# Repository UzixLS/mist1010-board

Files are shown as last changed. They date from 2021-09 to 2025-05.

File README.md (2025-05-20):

## MIST.1010
10x10cm PCB variant of [MIST FPGA](https://github.com/mist-devel/mist-board/wiki) project

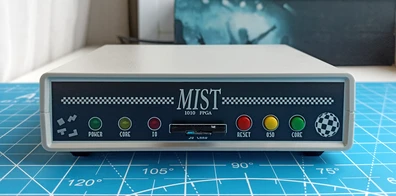
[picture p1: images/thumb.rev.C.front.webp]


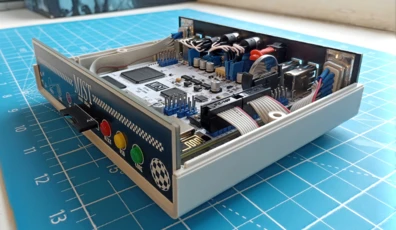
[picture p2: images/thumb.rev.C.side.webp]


[[More photos]](images/README.md)

Tech specs:
- EP3C25E144 FPGA
- 32/64Mb SDRAM
- VGA/RGB video output
- Composite video + audio output via 3.5 jack connector (raspberry-pi compatible pinout)
- 4xUSB ports for keyboard, mouse and joysticks
- 2xDB-9 ports for Amiga mouse and joysticks
- SD/microSD card slot
- RTC (clock) with battery
- Tape input / output
- ESP8266 WiFi module
- MIDI input and output (starting from rev.C)
- Type C (starting from rev.D) or MicroUSB power supply
- Board optimized for G738 and G706 cases

Some random photos: [link](https://cloud.err200.net/index.php/s/73TR85tYZkMm8Ax?path=%2Fmist1010)

### Changelog
* Rev.A - first revision. Please note the [errata](pcb/rev.A/ERRATA.txt).
* Rev.A1:
    * fixed all rev.A issues
    * LM3940IS-3.3 replaced to NCP1117-3.3
    * sound output circuit has been replaced with the original one from the MIST 1.3 circuit
    * C39, C40, C80 tantalum capacitors has been replaced by aluminum electrolytic capacitors
    * added ARM's "erase" testpoint
    * removed useless internal speaker
* Rev.A2:
	* C41, C68, C69 10uf ceramic capacitors has been replaced with 22uf tantalum
    * added C74 ceramic capacitor near ESP-01 module
* Rev.B:
    * added ESP-12E/F footprint (ESP-01 is still an option)
    * added MIDI input and output
    * removed U11 - AD724 encoder
    * added resistors-based CVBS (Y+C) video circuit
    * added JP4 solder jumper to disconnect CVBS circuit from 3.5mm jack
    * added U16 buffer with dedicated power source U17 for audio 1-bit DAC
    * added USB 2.54mm header
    * tuned SDRAM traces length for better match with MIST v1.3 PCB
    * changed U6 (attiny) footprint from DIP to SOIC
    * changed Y1 and Y2 footprints from THT to SMD
    * changed 1117-3.3 footprint from TO-252-2 to SOT-223-3
    * added U12 dedicated +3.3V power source for SD card and WiFi
    * 3mm front leds replaced by 5mm
    * R38 (VGA's +5V 0Ω resistor) has been replaced by solder jumper
    * changed tape header pinout
    * pcb corners are rounded now
    * experimental reset circuit based on MAX809
    * various changes in board layout
* Rev.C:
    * used USB Type C instead of Micro USB
    * PJ-320 3.5mm jack replaced by PJ-322
    * added solder jumper to select 3.5mm jack CVBS pinout
    * improved power distribution for FPGA chip
    * removed U16 buffer for DAC as it didn't bring any benefits
    * marked C27 and C28 as DNP
    * reverted to old reset circuit
    * various minor changes in board layout
* Rev.C1:
    * changed R47 from 220Ω to 1kΩ to reduce power led brightness
    * slightly moved C87 and C89

### Useful links
* MIST wiki: [link](https://github.com/mist-devel/mist-board/wiki)
* MIST cores and firmwares: [link](https://github.com/mist-devel/mist-binaries)

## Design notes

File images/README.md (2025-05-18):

# Gallery

## Revision C

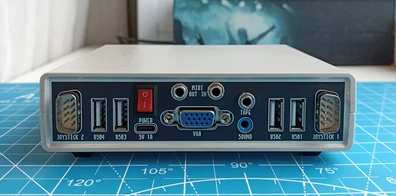
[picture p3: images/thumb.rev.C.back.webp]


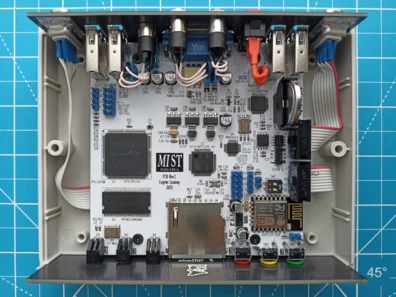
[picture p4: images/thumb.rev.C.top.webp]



## Revision B
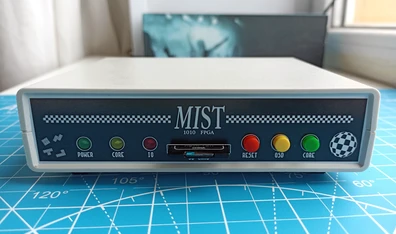
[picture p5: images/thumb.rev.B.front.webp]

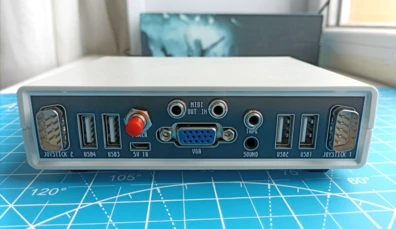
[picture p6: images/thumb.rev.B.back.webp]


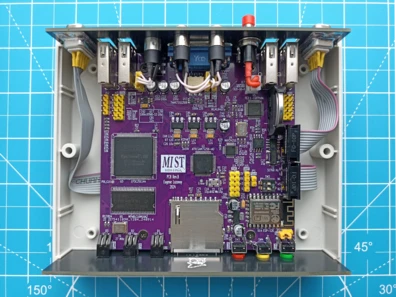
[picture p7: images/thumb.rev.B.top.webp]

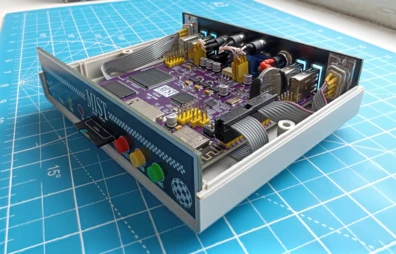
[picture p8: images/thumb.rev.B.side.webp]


## Revision A
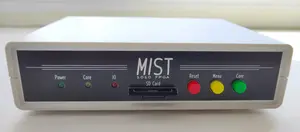
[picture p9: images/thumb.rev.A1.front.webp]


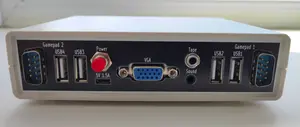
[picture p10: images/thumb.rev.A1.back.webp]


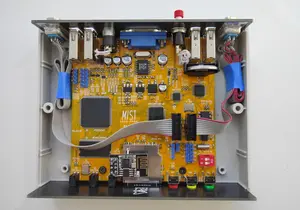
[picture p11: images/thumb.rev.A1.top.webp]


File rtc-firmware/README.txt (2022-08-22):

https://github.com/harbaum/I2C-Tiny-USB

Fuse Low Byte: 0xE0
Fuse High Byte: 0x5D

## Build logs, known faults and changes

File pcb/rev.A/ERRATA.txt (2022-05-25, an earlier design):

1. VGA_x0 .. VGA_x5 resistors are reversed by value. Should be:
   VGA_x5 - 1k + 1.1k in parallel
   VGA_x4 - 1.1k
   VGA_x3 - 2.2k
   VGA_x2 - 4.3k
   VGA_x1 - 9.1k
   VGA_x0 - 18k
2. USB_DP and USB_DN signals are swapped.
3. R49 is connected to RTC_DP net, should be RTC_DN.
4. USB, VGA and jack 3.5 connectors are placed too deep. Jack 3.5 should be soldered 2-3mm ahead it's footprint.
5. LS1 shouldn't be mounted.
6. Tape and WiFi isn't possible to use at the same time. If you want to install WiFi module - do not mount R59.

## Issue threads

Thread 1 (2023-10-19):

Some help needed with Audio jack connection for tape.

AmiManga, 2023-10-19:
Hello,
I am trying to figure out how wo connect tape connector and how to make the audio cable?
I assume this is stereo jack? Where does the TAPE_OUT go? And how about TAPE_IN?
Should I split this after to two mono jacks like this? : https://www.ebay.ca/itm/383787499804

Is this correct?

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

Cheers,

Ranko

UzixLS, 2023-10-21:
Which cable to use / how to make cable - it completely depends on your tape equipment, see it's manual.
In MIST 1010 tape in/out is populated just on pin header, so can be connected in any way you need.

AmiManga, 2023-10-22:
Thank you for your reply. So if I understand correctly, TAPE_OUT goes to MIC (on the cassette player) and TAPE_IN goes to EAR (on the cassette player)? Is this correct? OR other way around?

Cheers,

R.

UzixLS, 2023-10-24:
This is probably correct.

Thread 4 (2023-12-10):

RTC implementation?

AmiManga, 2023-12-10:
Regarding RTC,

I was able to setup the time and it works just fine!
However while system is off, clock does not measure time, just remembers time when system was powered off.
Is this proper behaviour or am I missing something? Should clock run all the time?

Cheers,

R.

UzixLS, 2023-12-10:
RTC should count time even when system powered off.
Check battery voltage - it must be between 2.0V and 3.5V for proper operation.

AmiManga, 2023-12-10:
It appears that there was a firmware corruption in the ATtiny45. Fortunately, after re-flashing the firmware, everything is functioning correctly even after powering off. I recall that the clock initially performed well in offline mode. Glad to know it wasn't just my imagination!

Thank you

R.

Closed 2023-12-10.

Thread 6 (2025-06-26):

Trouble loading fpga core

svpantazi, 2025-06-26:
Hello,

I am trying to boot MIST1010. The FPGA NSTATUS does not change to OK and i receive Fatal error 3 (3 blinks, one longer +2 short).  I used a AT91SAM7S512 (512kb Flash) instead of the 256 kb in the schematic and the alternative micro SD card slot footprint (I notice that does not come with a SD_WP pin). The parts are identical as far as I can tell, except for the amount of Flash. I also prepared an SD card, according to instructions. I am looking for any suggestions you may have.
Below is the serial debug I receive:

Minimig by Dennis van Weeren
ARM Controller by Jakub Bednarski

Version ATH250604

SDHC card detected
spiclk: 24 MHz
usb_init
usb_hw_init
max3421e_init()
Chip revision: 13
busprobe()
usb_reset_state
Partition Count: 1
Partition: 0  Start: 8192  Size: 62325760
Partition type: EXFAT
fat_size: 7616
fat_number: 1
fat_start: 10240
root_directory_start: 7
dir_entries: 0
data_start: 18432
cluster_size: 64
free_clusters: 4294967295
ChangeDirectoryName: / -> / = /
Loading SYSTEM.FNT
Invalid SYSTEM.FNT size!
debug_mode = 0
INI_PARSER : Can't open file /CORE.ARC !
ARC CONF STR:
INI_PARSER : Can't open file /MISTCFG.INI !
loaded_from_usb = 0
FPGA bitstream file CORE.RBF opened, file size = 385575
[FPGA NSTATUS is NOT high!
Fatal error: 3

svpantazi, 2025-06-26:
Nevermind, the trouble with loading FPGA core and the errors above was simply caused by my not soldering the FPGA bottom pad to the board.

Closed 2025-06-26.

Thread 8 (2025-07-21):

RTC not work !

nicolaebizi, 2025-07-21:
Hello
Today I turned on the MIST1010 and I have only one problem! The clock counts the seconds from 80 to 139, and if I turn off the power it stays there and doesn't continue counting.

nicolaebizi, 2025-07-23:
This proves that in the firmware register 0 with bit 7 is sent to the display, in the Arduino library it is corrected -&x7f- and then ok is displayed for the second.
Don't beat around the bush if it's not like that, I'm a beginner!

svpantazi, 2025-07-23:
After inspecting the code and serial debug messages from AT91 firmware it appears that all USB device classes are indeed supposed to be initialized in the usb_configure() call. initializing USB classes proceds in this order, the hub class that ends up no accepted (with "not a hub!" message) followed by the usb HID class which manages to initialize the keyboard and mouse. Initialization of the other classes listed (xbox, asix, storage, usbrtc and pl2003) depends strongly of what is plugged into the hub and can be chaotic at times, only to be settled by additional resets. I am suggesting that listing the usbrtc earlier in the list (currently at index 5 in the list, since storage class is not enabled), maybe even before HID, may accomplish something (list the current date and time) but not the CH bit initialization which may need to be done once only to enable the clock oscillator.

** serial debug excerpt:
[...]
trying to init class 0
usb_hub_init()
not a hub!
 -> not accepted :-(
trying to init class 1
HID: usb_hid_init(3)
HID: iface is HID
HID: HID protocol is MOUSE
HID:  -> report descriptor size = 46
HID: endpoint 1, interval = 10ms
HID: HID report descriptor:
0000: 05 01 09 02 a1 01 09 01 a1 00 05 09 19 01 29 03   ..............).
0010: 15 00 25 01 95 08 75 01 81 02 05 01 09 30 09 31   ..%.�.u.�....0.1
0020: 09 38 15 81 25 7f 75 08 95 03 81 06 c0 c0         .8.�%.u.�����.�.��
HIDP: USAGE_PAGE(1/0x1)
HIDP:  -> Generic Desktop

*** [multiple HID mesages]

HIDP:   - report 0 is usable
MOUSE: report type = 1, id = 0, size = 4
HID configured
 -> accepted :-)
status change on port 5, 0x10301
Status of port 5:
 connected
 powered
 low speed
Changes on port 5:
 connected
 dev 1: port 5 connect!
usb_release_device(parent=1, port=5
resetting port 5
status change on port 5, 0x100303
Status of port 5:
 connected
 enabled
 powered
 low speed
Changes on port 5:
 reset
 port 5 reset complete!
usb_configure(parent=1 port=5 lowspeed=1)
using free entry at 3
Setting addr 4
usb_set_addr(new=4)
USB vendor ID: 0403, product ID: C631
wLangId: 0409
trying to init class 0
usb_hub_init()
not a hub!
 -> not accepted :-(
trying to init class 1
HID: usb_hid_init(4)
HID: no hid interfaces found
 -> not accepted :-(
trying to init class 2
 -> not accepted :-(
trying to init class 3
 -> not accepted :-(
trying to init class 4
 -> not accepted :-(
trying to init class 5
time: 19:07:80
date: 18.07.25
 -> accepted :-)
** end of serial debug

As others reported, it appears that the entered date and time date is being stored and persists but RTC does no update. Which prompted me to actually set the seconds value to 0, which made the clock start!

nicolaebizi, 2025-07-23:
ok

Closed 2025-07-23.

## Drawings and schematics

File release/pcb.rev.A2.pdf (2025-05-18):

1 | 2 | 3 | 4 | 5 | 6 | 7 | 8 | 9 | 10

A

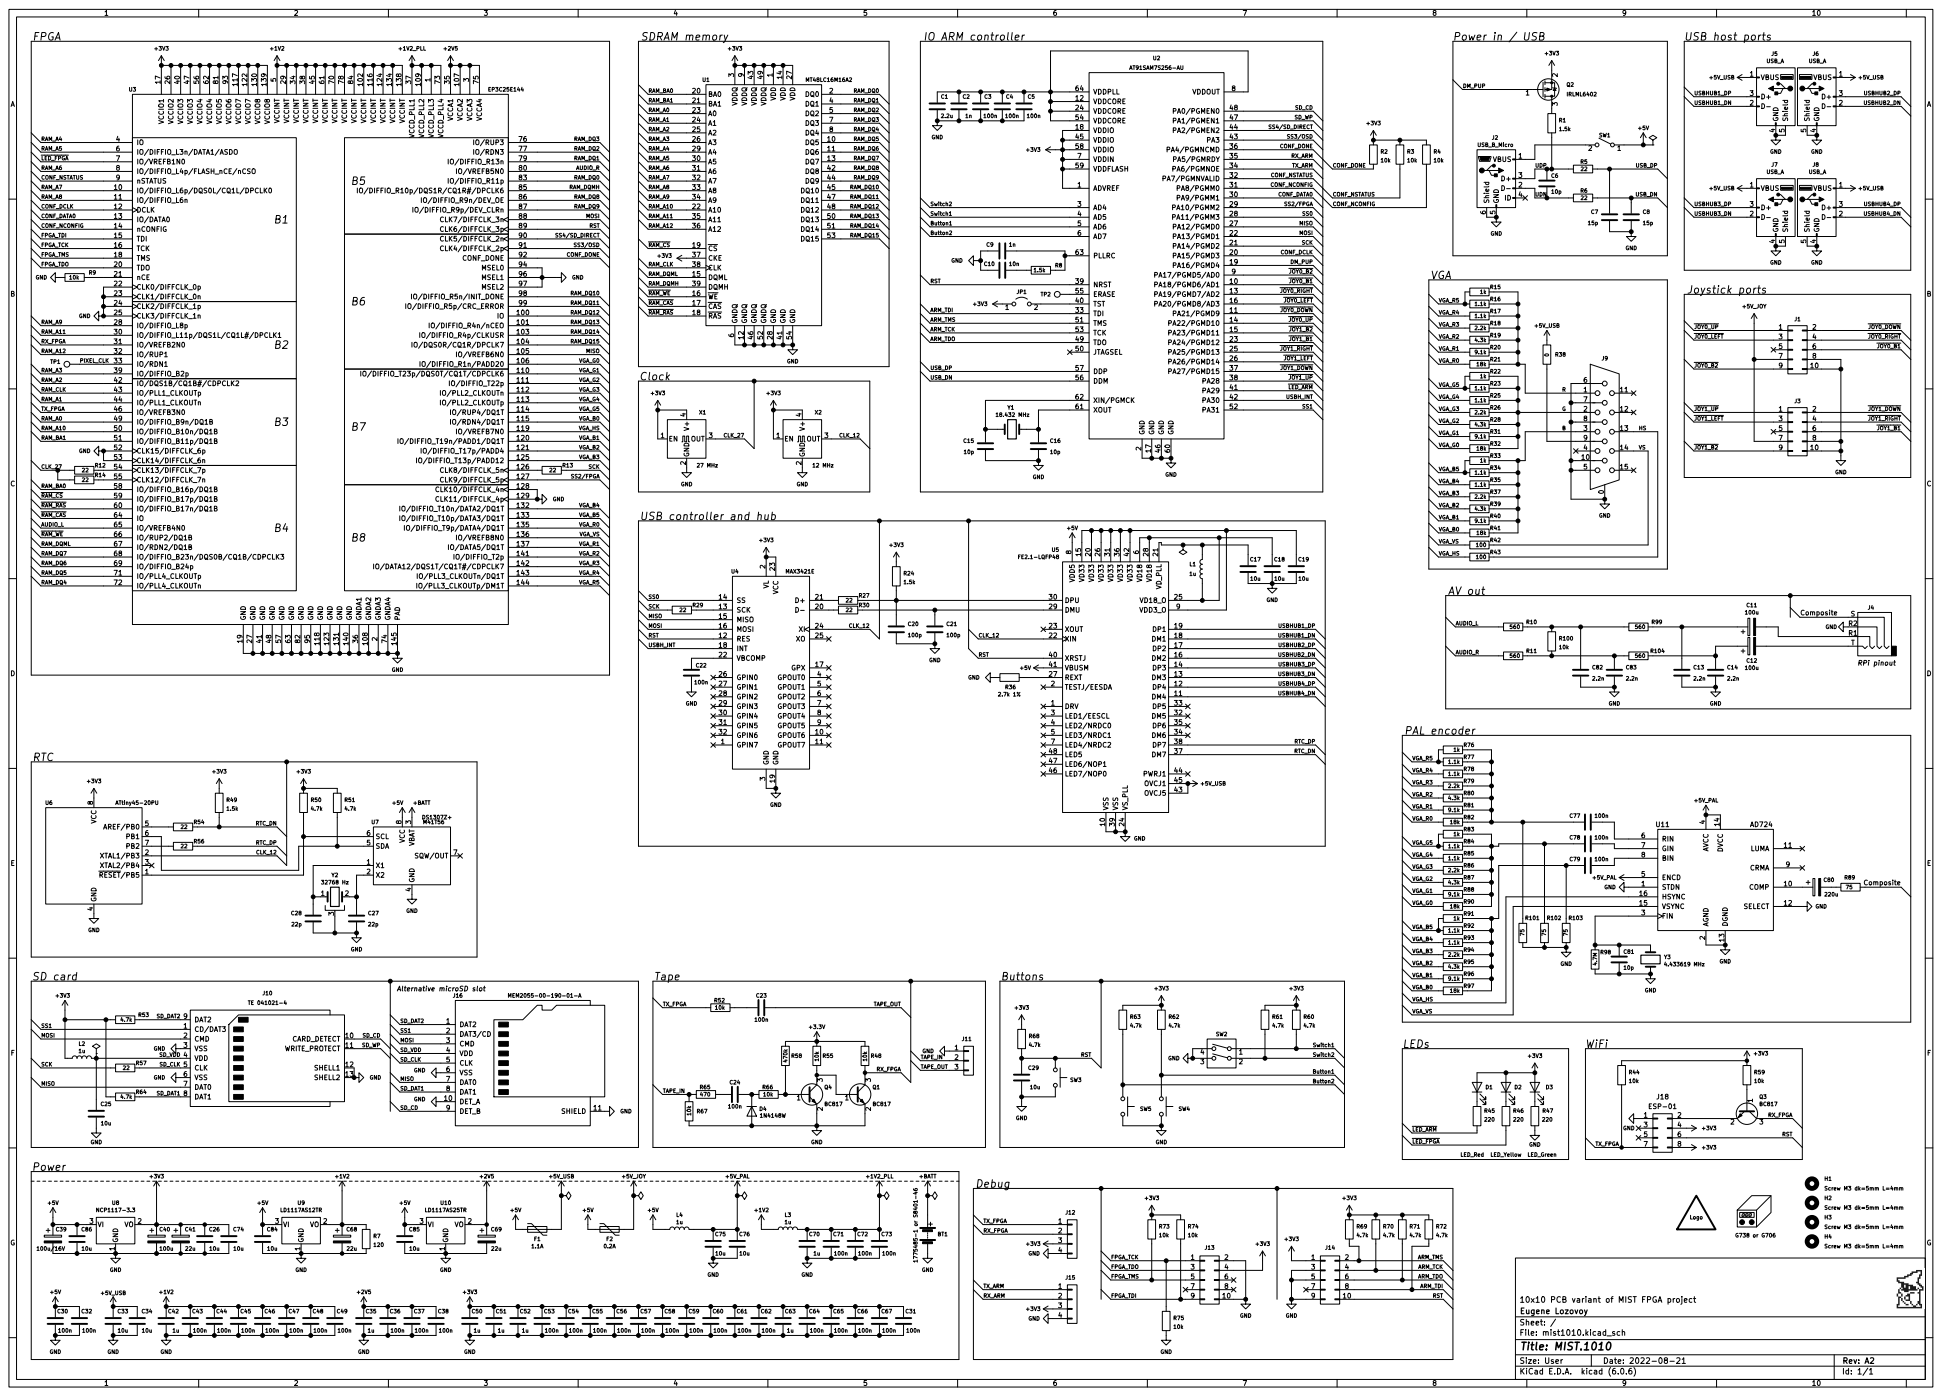
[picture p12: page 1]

USB controller and hub

10x10 PCB variant of MIST FPGA project
Eugene Lozovoy

1 | 2 | 3 | 4 | 5 | 6

A

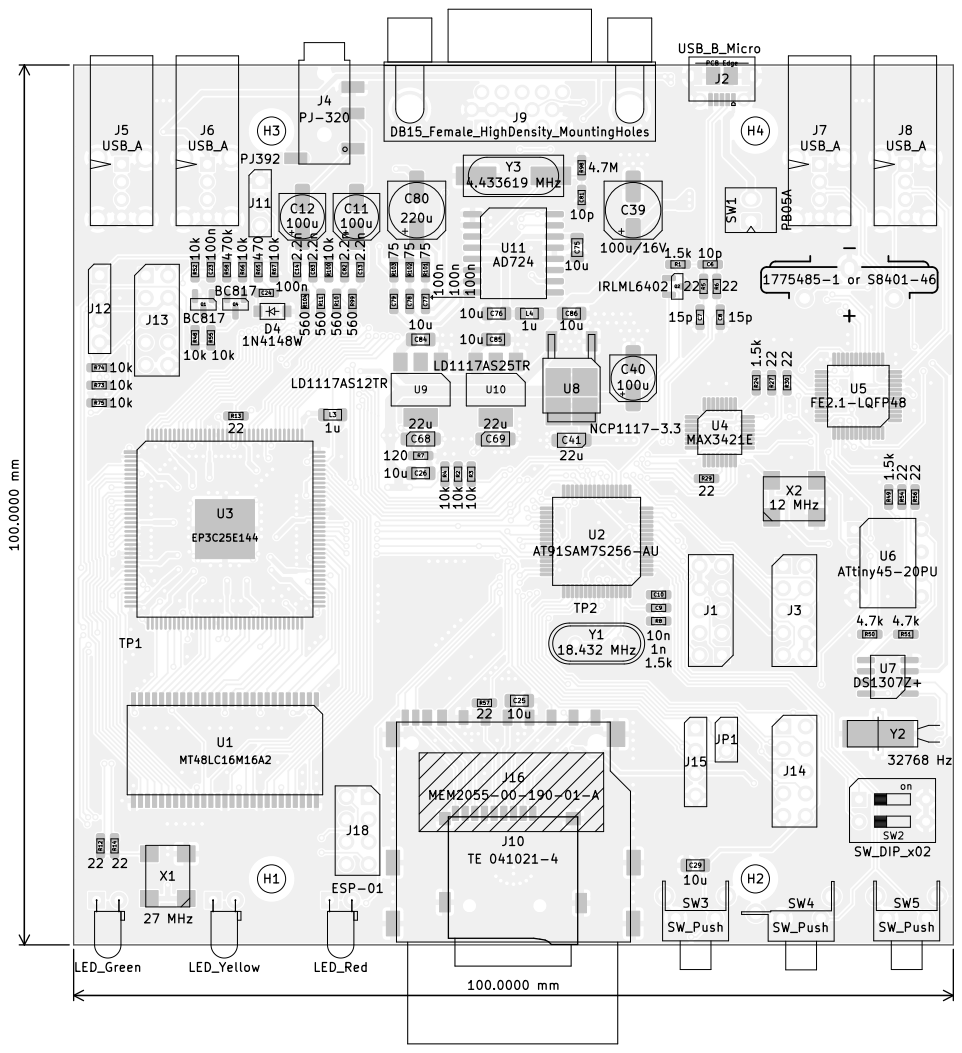
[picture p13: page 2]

1

2

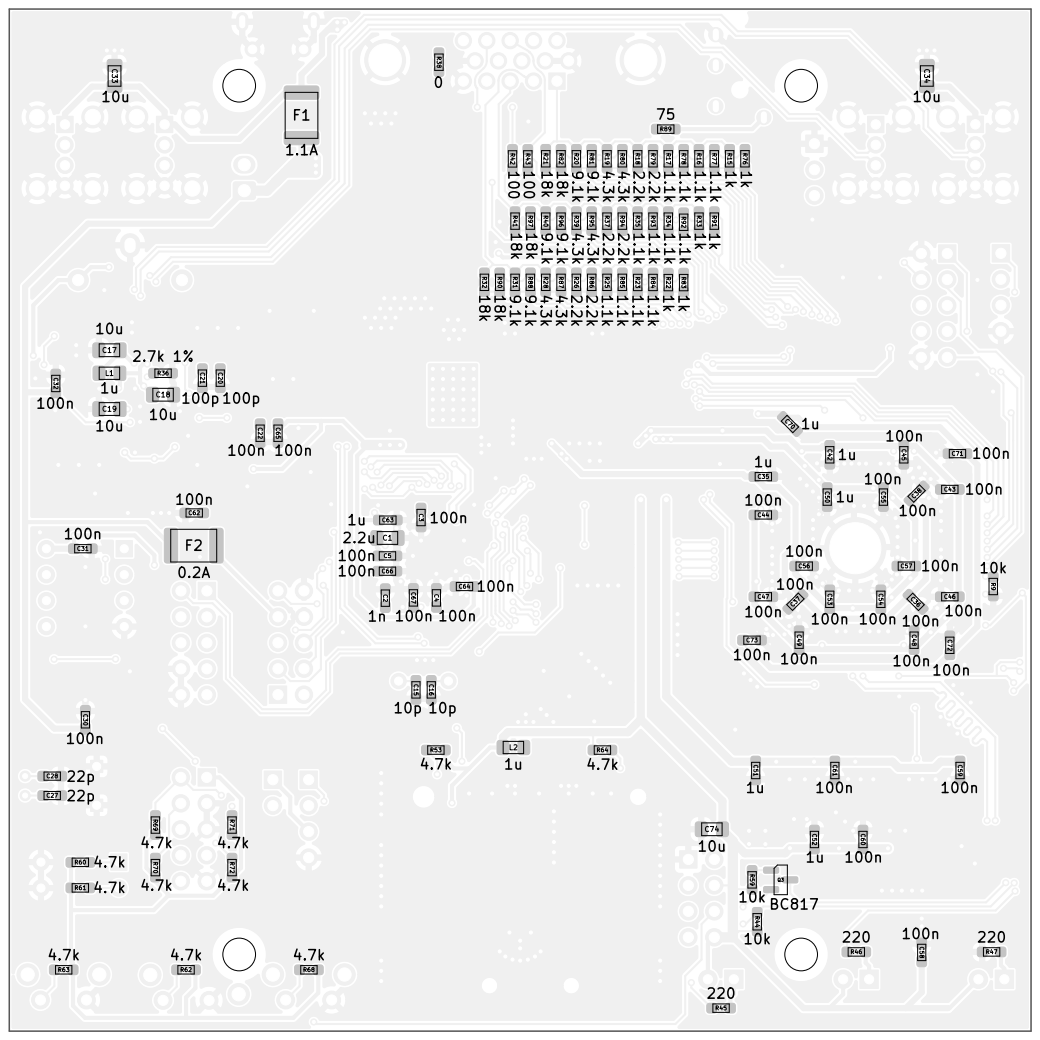
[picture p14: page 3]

Designator | Package | Value | Quantity
BT1 | CR2032V | 1775485-1 or S8401-46 | 1
C1 | C_0805_2012Metric_Pad1.18x1.45mm_HandSolder | 2.2u | 1
C2, C9 | C_0603_1608Metric_Pad1.08x0.95mm_HandSolder | 1n | 2
C3, C4, C5, C22, C23, C24, C30, C31, C32, C36, C37, C38, C43, C44, C45, C46, C47, C48, C49, C53, C54, C55, C56, C57, C58, C59, C60, C61, C62, C64, C65, C66, C67, C71, C72, C73, C77, C78, C79 | C_0603_1608Metric_Pad1.08x0.95mm_HandSolder | 100n | 39
C6, C15, C16, C81 | C_0603_1608Metric_Pad1.08x0.95mm_HandSolder | 10p | 4
C7, C8 | C_0603_1608Metric_Pad1.08x0.95mm_HandSolder | 15p | 2
C10 | C_0603_1608Metric_Pad1.08x0.95mm_HandSolder | 10n | 1
C11, C12, C40 | CP_Elec_5x5.9 | 100u | 3
C13, C14, C82, C83 | C_0603_1608Metric_Pad1.08x0.95mm_HandSolder | 2.2n | 4
C17, C18, C19, C25, C26, C29, C33, C34, C74, C75, C76, C84, C85, C86 | C_0805_2012Metric_Pad1.18x1.45mm_HandSolder | 10u | 14
C20, C21 | C_0603_1608Metric_Pad1.08x0.95mm_HandSolder | 100p | 2
C27, C28 | C_0603_1608Metric_Pad1.08x0.95mm_HandSolder | 22p | 2
C35, C42, C50, C51, C52, C63, C70 | C_0603_1608Metric_Pad1.08x0.95mm_HandSolder | 1u | 7
C39 | CP_Elec_6.3x7.7 | 100u/16V | 1
C41, C68, C69 | CP_EIA-3216-18_Kemet-A_Pad1.58x1.35mm_HandSolder | 22u | 3
C80 | CP_Elec_6.3x7.7 | 220u | 1
D1 | LED_D3.0mm_Horizontal_O1.27mm_Z6.0mm | LED_Red | 1
D2 | LED_D3.0mm_Horizontal_O1.27mm_Z6.0mm | LED_Yellow | 1
D3 | LED_D3.0mm_Horizontal_O1.27mm_Z6.0mm | LED_Green | 1
D4 | D_SOD-123 | 1N4148W | 1
F1 | Fuse_1812_4532Metric_Pad1.30x3.40mm_HandSolder | 1.1A | 1
F2 | Fuse_1812_4532Metric_Pad1.30x3.40mm_HandSolder | 0.2A | 1
H1, H2, H3, H4 | MountingHole_3.2mm_M3_dk5.2mm | Screw M3 dk=5mm L=4mm | 4
J1, J3, J13, J14 | PinHeader_2x05_P2.54mm_Vertical | Conn_02x05_Odd_Even | 4
J2 | USB_Micro-B_Molex-105017-0001 | USB_B_Micro | 1
J4 | PJ-320A_D | PJ-320 | 1
J5, J6, J7, J8 | USB_A_Wuerth_614004134726_Horizontal | USB_A | 4
J9 | DSUB-15-HD_Female_Horizontal_P2.29x1.98mm_EdgePinOffset 3.03mm_Housed_MountingHolesOffset4.94mm | DB15_Female_HighDensity_M ountingHoles | 1
J10 | SD_TE_2041021-mod | TE 041021-4 | 1
J11 | PinHeader_1x03_P2.54mm_Vertical | PJ392 | 1
J12, J15 | PinHeader_1x04_P2.54mm_Vertical | Conn_01x04 | 2
J16 | GCT-MEM2055-00-190-01-A | MEM2055-00-190-01-A | 1
J18 | PinSocket_2x04_P2.54mm_Vertical | ESP-01 | 1
JP1 | PinHeader_1x02_P2.54mm_Vertical | Jumper_2_Open | 1
L1, L2, L3, L4 | L_0805_2012Metric_Pad1.15x1.40mm_HandSolder | 1u | 4
N1 | | G738 or G706 | 1
Q1, Q3, Q4 | SOT-23 | BC817 | 3
Q2 | SOT-23 | IRLML6402 | 1
R1, R8, R24, R49 | R_0603_1608Metric_Pad0.98x0.95mm_HandSolder | 1.5k | 4
R2, R3, R4, R9, R44, R48, R52, R55, R59, R66, R67, R73, R74, R75, R100 | R_0603_1608Metric_Pad0.98x0.95mm_HandSolder | 10k | 15
R5, R6, R12, R13, R14, R27, R29, R30, R54, R56, R57 | R_0603_1608Metric_Pad0.98x0.95mm_HandSolder | 22 | 11
R7 | R_0603_1608Metric_Pad0.98x0.95mm_HandSolder | 120 | 1
R10, R11, R99, R104 | R_0603_1608Metric_Pad0.98x0.95mm_HandSolder | 560 | 4
R15, R22, R33, R76, R83, R91 | R_0603_1608Metric_Pad0.98x0.95mm_HandSolder | 1k | 6
R16, R17, R23, R25, R34, R35, R77, R78, R84, R85, R92, R93 | R_0603_1608Metric_Pad0.98x0.95mm_HandSolder | 1.1k | 12
R18, R26, R37, R79, R86, R94 | R_0603_1608Metric_Pad0.98x0.95mm_HandSolder | 2.2k | 6
R19, R28, R39, R80, R87, R95 | R_0603_1608Metric_Pad0.98x0.95mm_HandSolder | 4.3k | 6
R20, R31, R40, R81, R88, R96 | R_0603_1608Metric_Pad0.98x0.95mm_HandSolder | 9.1k | 6
R21, R32, R41, R82, R90, R97 | R_0603_1608Metric_Pad0.98x0.95mm_HandSolder | 18k | 6
R36 | R_0603_1608Metric_Pad0.98x0.95mm_HandSolder | 2.7k 1% | 1
R38 | R_0603_1608Metric_Pad0.98x0.95mm_HandSolder | 0 | 1
R42, R43 | R_0603_1608Metric_Pad0.98x0.95mm_HandSolder | 100 | 2
R45, R46, R47 | R_0603_1608Metric_Pad0.98x0.95mm_HandSolder | 220 | 3
R50, R51, R53, R60, R61, R62, R63, R64, R68, R69, R70, R71, R72 | R_0603_1608Metric_Pad0.98x0.95mm_HandSolder | 4.7k | 13
R58 | R_0603_1608Metric_Pad0.98x0.95mm_HandSolder | 470k | 1
R65 | R_0603_1608Metric_Pad0.98x0.95mm_HandSolder | 470 | 1
R89, R101, R102, R103 | R_0603_1608Metric_Pad0.98x0.95mm_HandSolder | 75 | 4
R98 | R_0603_1608Metric_Pad0.98x0.95mm_HandSolder | 4.7M | 1
SW1 | Molex_KK-254_AE-6410-02A_1x02_P2.54mm_Vertical | PB05A | 1
SW2 | SW_DIP_SPSTx02_Slide_9.78x7.26mm_W7.62mm_P 2.54mm | SW_DIP_x02 | 1
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

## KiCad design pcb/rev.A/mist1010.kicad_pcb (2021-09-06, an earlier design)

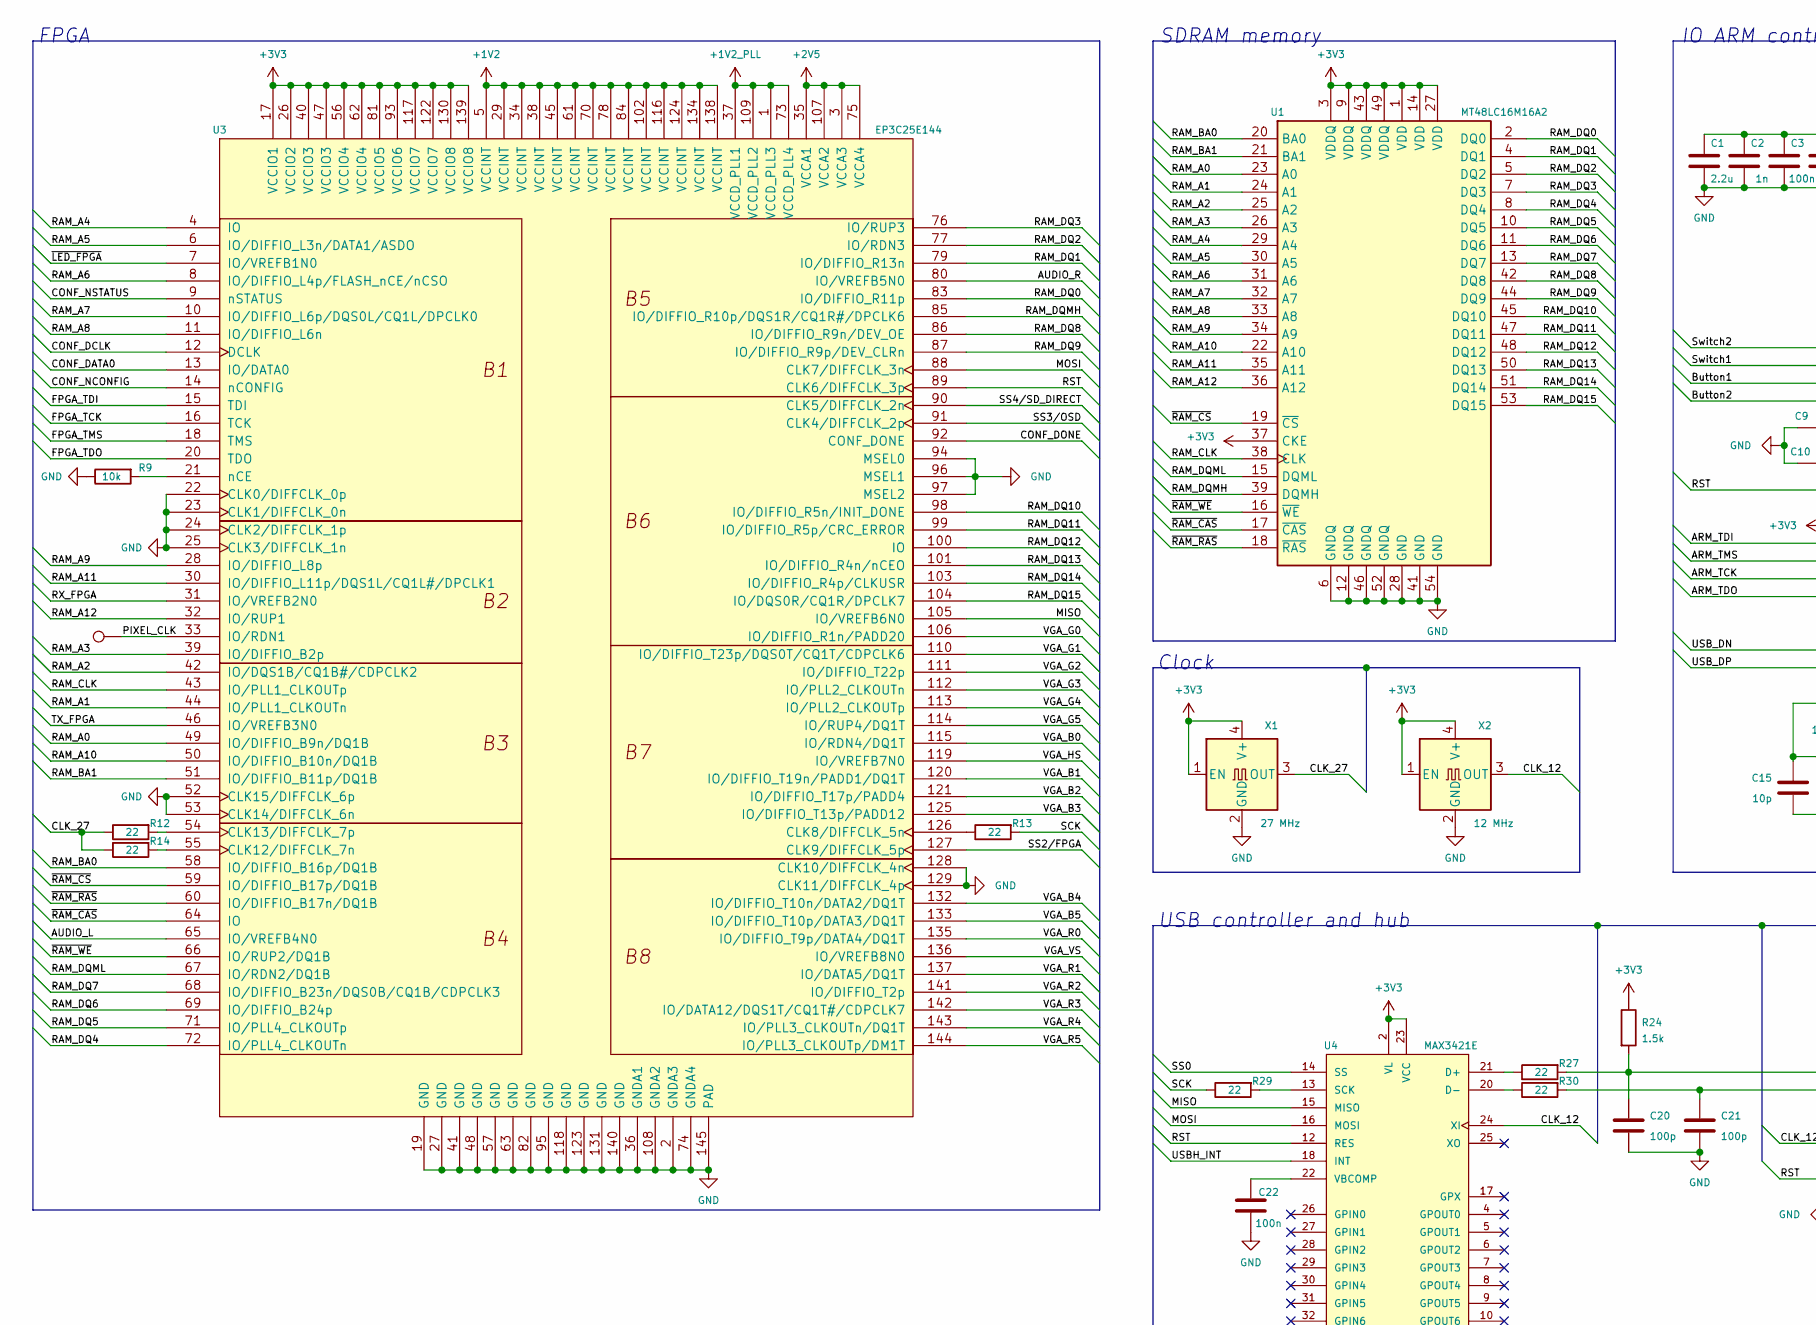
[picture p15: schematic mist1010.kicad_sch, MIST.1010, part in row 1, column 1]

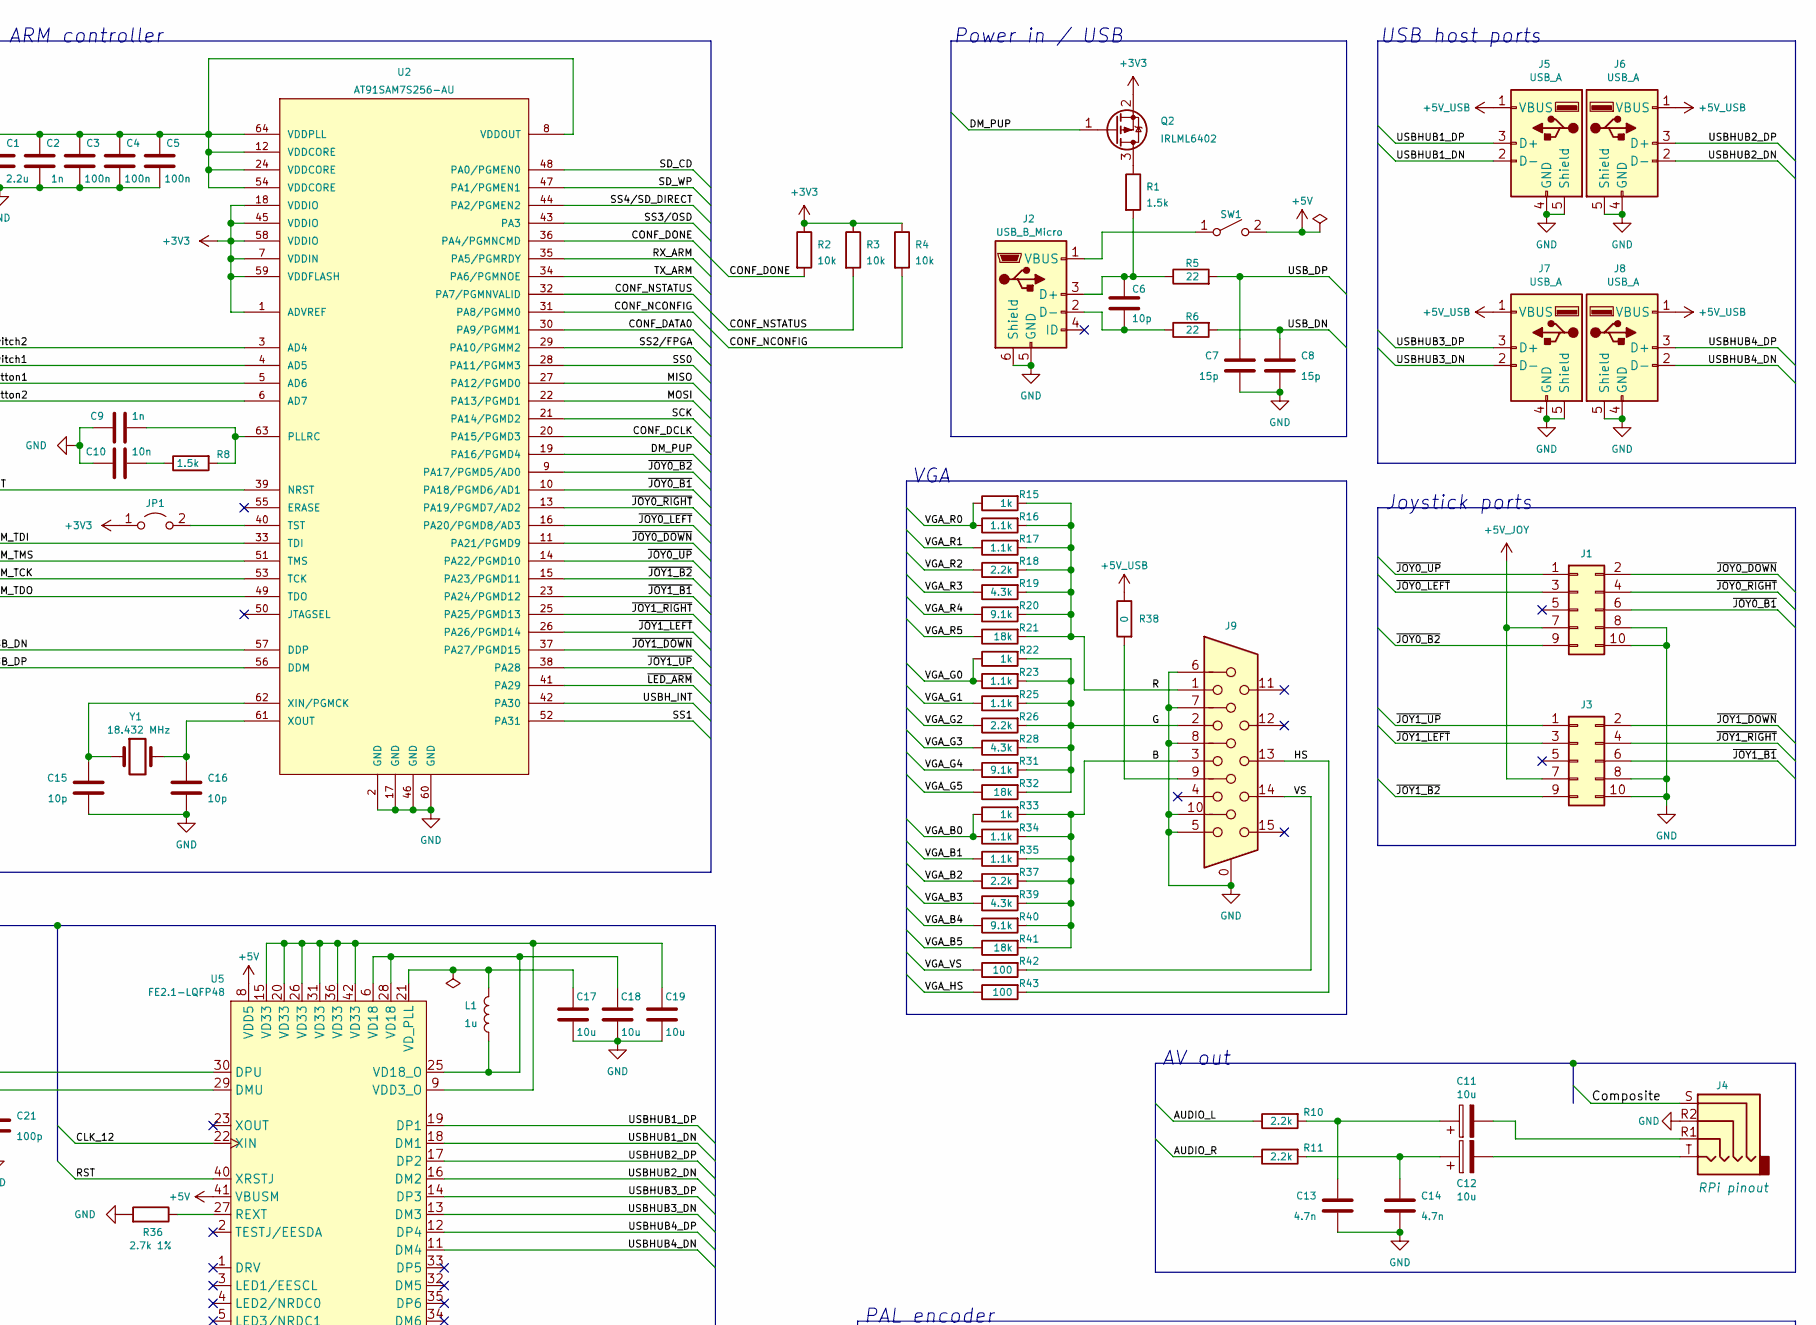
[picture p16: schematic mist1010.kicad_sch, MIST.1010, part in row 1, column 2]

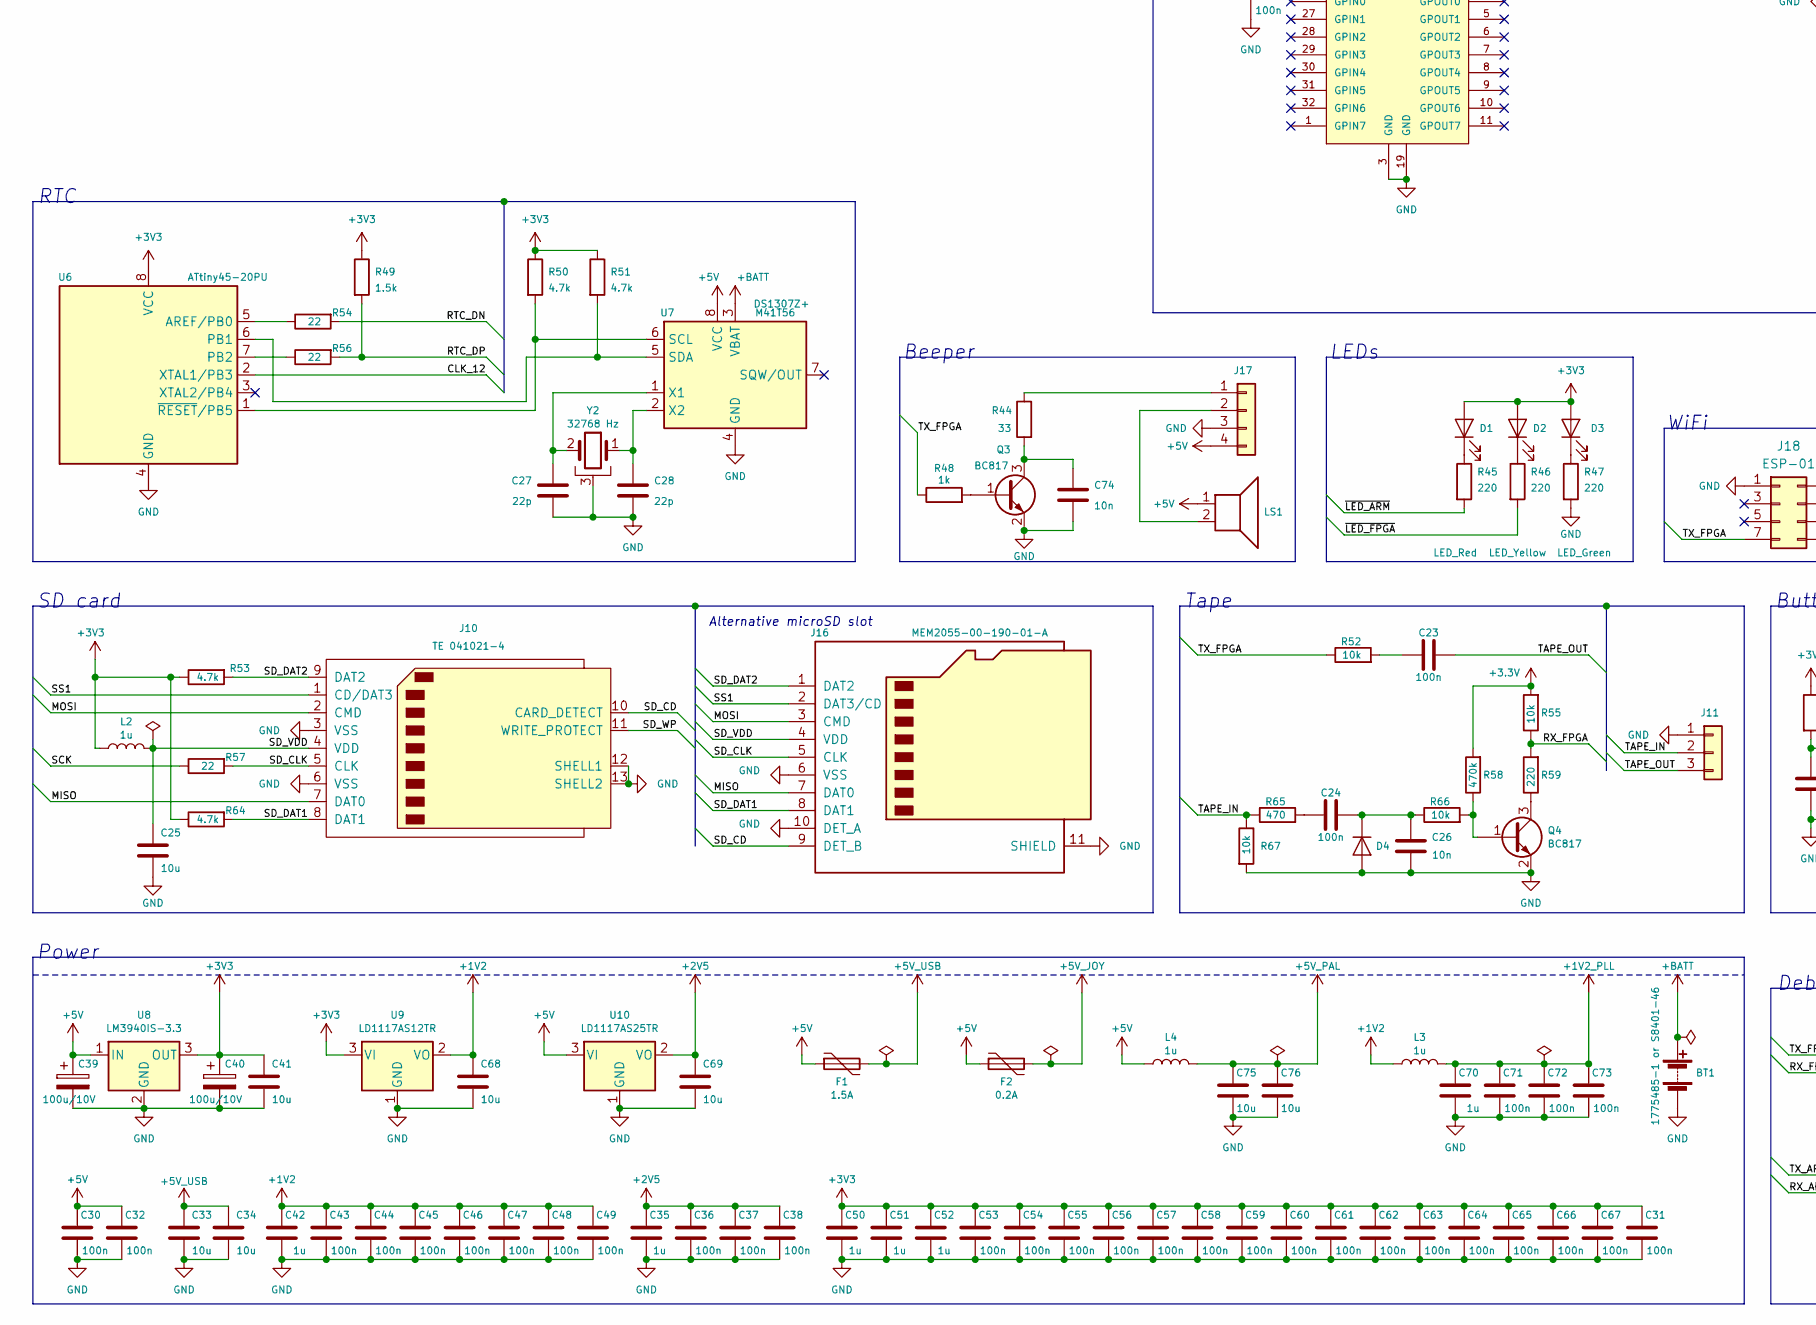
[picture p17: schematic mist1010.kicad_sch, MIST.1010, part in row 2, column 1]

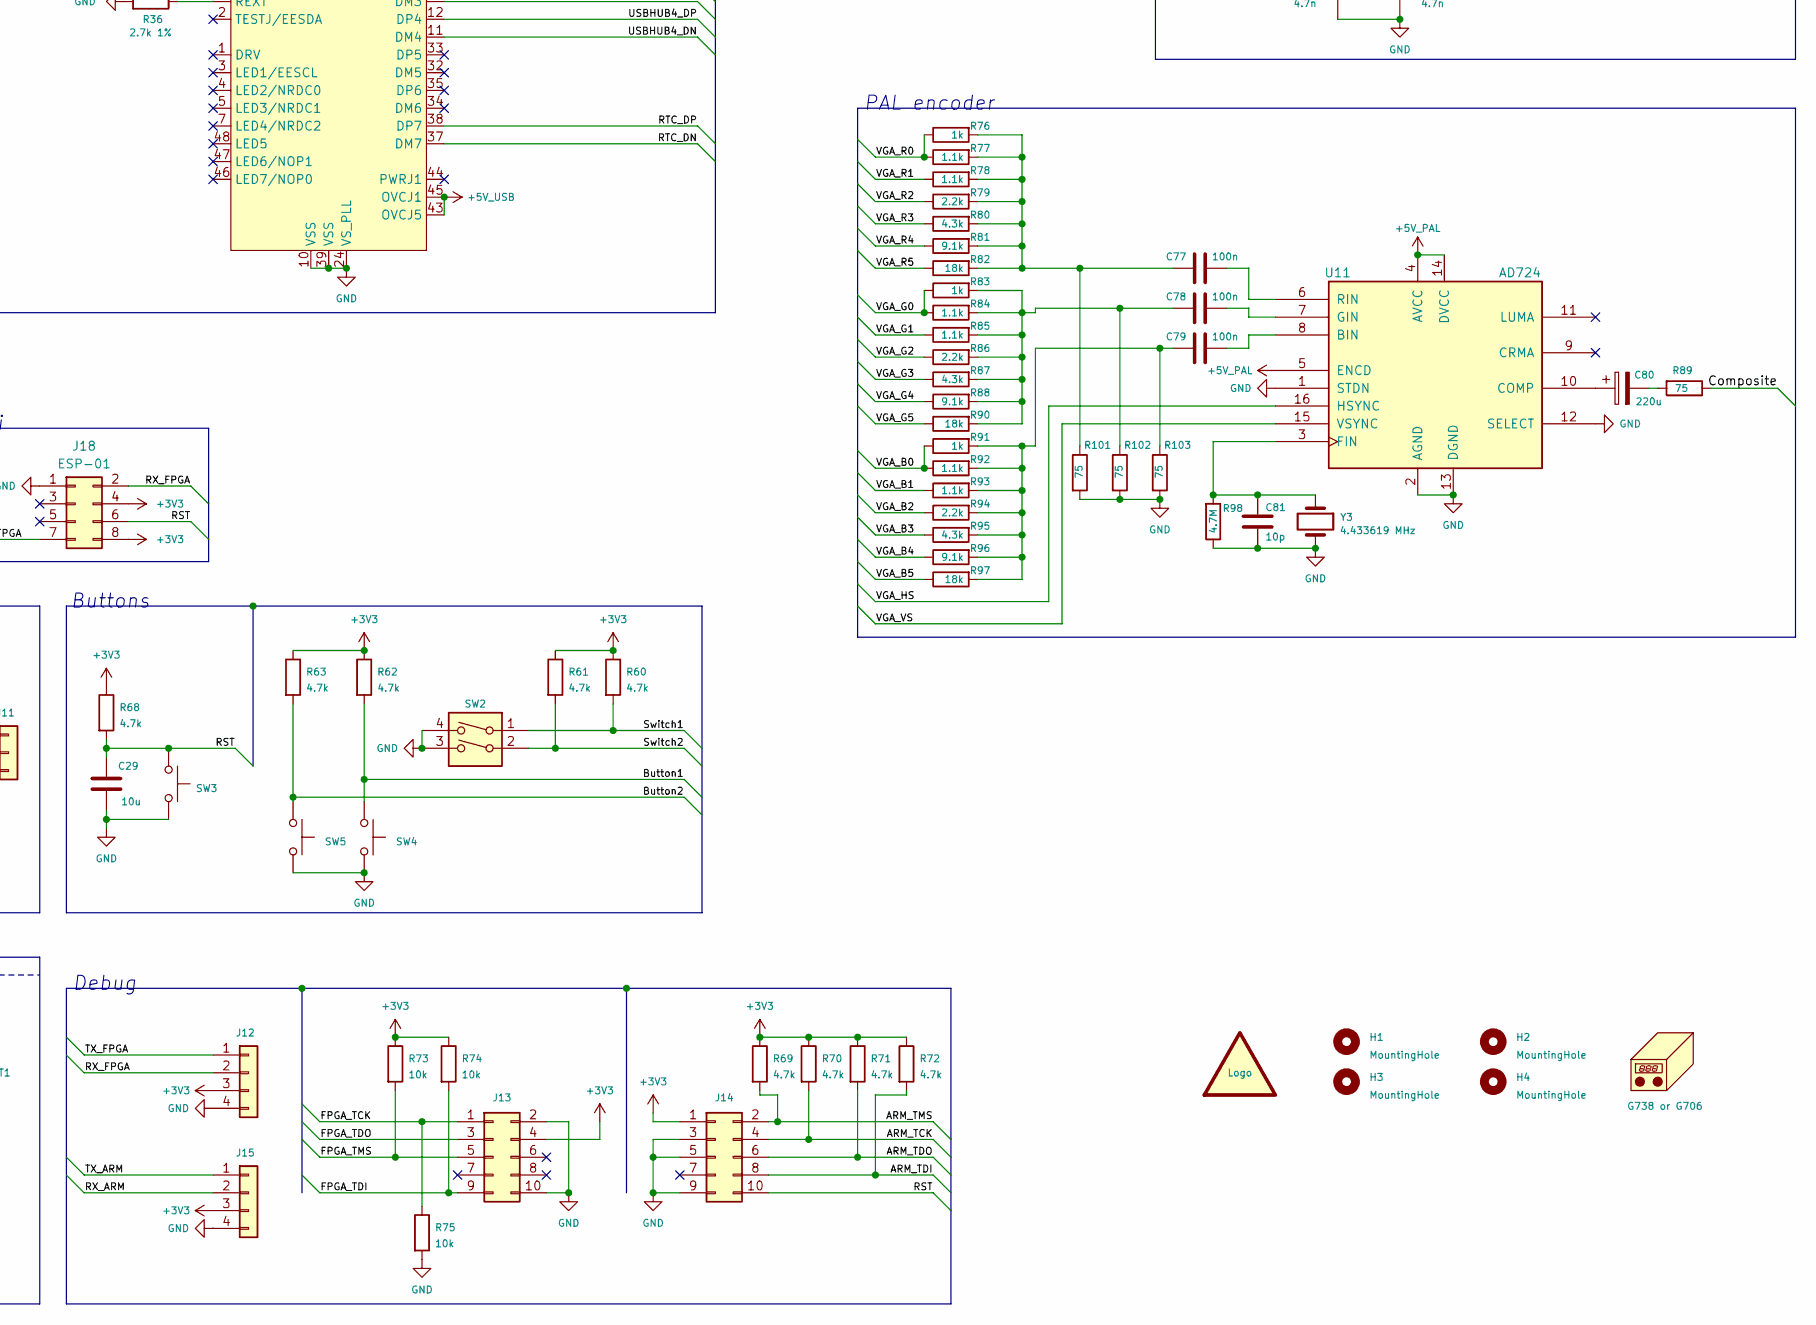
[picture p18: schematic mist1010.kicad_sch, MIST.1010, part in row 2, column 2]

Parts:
BT1: 1775485-1 or S8401-46; CR2032V
C1: 2.2u; C_0805_2012Metric_Pad1.18x1.45mm_HandSolder
C2, C9: 1n; C_0603_1608Metric_Pad1.08x0.95mm_HandSolder
C3, C4, C5, C22, C23, C24, C30, C31, C32, C36, C37, C38, C43, C44, C45, C46, C47, C48, C49, C53, C54, C55, C56, C57, C58, C59, C60, C61, C62, C63, C64, C65, C66, C67, C71, C72, C73, C77, C78, C79: 100n; C_0603_1608Metric_Pad1.08x0.95mm_HandSolder
C6, C15, C16, C81: 10p; C_0603_1608Metric_Pad1.08x0.95mm_HandSolder
C7, C8: 15p; C_0603_1608Metric_Pad1.08x0.95mm_HandSolder
C10, C26, C74: 10n; C_0603_1608Metric_Pad1.08x0.95mm_HandSolder
C11, C12: 10u; CP_Elec_4x5.4
C13, C14: 4.7n; C_0603_1608Metric_Pad1.08x0.95mm_HandSolder
C17, C18, C19, C25, C29, C33, C34, C41, C68, C69, C75, C76: 10u; C_0805_2012Metric_Pad1.18x1.45mm_HandSolder
C20, C21: 100p; C_0603_1608Metric_Pad1.08x0.95mm_HandSolder
C27, C28: 22p; C_0603_1608Metric_Pad1.08x0.95mm_HandSolder
C35, C42, C50, C51, C52, C70: 1u; C_0603_1608Metric_Pad1.08x0.95mm_HandSolder
C39, C40: 100u/10V; CP_EIA-7343-31_Kemet-D_Pad2.25x2.55mm_HandSolder
C80: 220u; CP_EIA-7343-31_Kemet-D
D1: LED_Red; LED_D3.0mm_Horizontal_O1.27mm_Z6.0mm
D2: LED_Yellow; LED_D3.0mm_Horizontal_O1.27mm_Z6.0mm
D3: LED_Green; LED_D3.0mm_Horizontal_O1.27mm_Z6.0mm
D4: 1N4148W; D_SOD-123
F1: 1.5A; Fuse_1812_4532Metric_Pad1.30x3.40mm_HandSolder
F2: 0.2A; Fuse_1812_4532Metric_Pad1.30x3.40mm_HandSolder
H1, H2, H3, H4: MountingHole; MountingHole_3.2mm_M3_ISO14580
J1, J3, J13, J14: Conn_02x05_Odd_Even; PinHeader_2x05_P2.54mm_Vertical
J2: USB_B_Micro; USB_Micro-B_Molex-105017-0001
J4: PJ-320; PJ-320A_D
J5, J6, J7, J8: USB_A; USB_A_Wuerth_614004134726_Horizontal
J9: DB15_Female_HighDensity_MountingHoles; DSUB-15-HD_Female_Horizontal_P2.29x1.98mm_EdgePinOffset3.03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
J10: TE 041021-4; SD_TE_2041021-mod
J11: Conn_01x03; PinHeader_1x03_P2.54mm_Vertical
J12, J15, J17: Conn_01x04; PinHeader_1x04_P2.54mm_Vertical
J16: MEM2055-00-190-01-A; GCT-MEM2055-00-190-01-A
J18: ESP-01; PinSocket_2x04_P2.54mm_Vertical
JP1: Jumper_2_Open; PinHeader_1x02_P2.54mm_Vertical
L1, L2, L3, L4: 1u; L_0805_2012Metric_Pad1.15x1.40mm_HandSolder
LOGO1: graphic; black-mage-6.7x9.5
LS1: Speaker; Buzzer_12x9.5RM7.6
N1: G738 or G706
Q2: IRLML6402; SOT-23
Q3, Q4: BC817; SOT-23
R1, R8, R24, R49: 1.5k; R_0603_1608Metric_Pad0.98x0.95mm_HandSolder
R2, R3, R4, R9, R52, R55, R66, R67, R73, R74, R75: 10k; R_0603_1608Metric_Pad0.98x0.95mm_HandSolder
R5, R6, R12, R13, R14, R27, R29, R30, R54, R56, R57: 22; R_0603_1608Metric_Pad0.98x0.95mm_HandSolder
R10, R11, R18, R26, R37, R79, R86, R94: 2.2k; R_0603_1608Metric_Pad0.98x0.95mm_HandSolder
R15, R22, R33, R48, R76, R83, R91: 1k; R_0603_1608Metric_Pad0.98x0.95mm_HandSolder
R16, R17, R23, R25, R34, R35, R77, R78, R84, R85, R92, R93: 1.1k; R_0603_1608Metric_Pad0.98x0.95mm_HandSolder
R19, R28, R39, R80, R87, R95: 4.3k; R_0603_1608Metric_Pad0.98x0.95mm_HandSolder
R20, R31, R40, R81, R88, R96: 9.1k; R_0603_1608Metric_Pad0.98x0.95mm_HandSolder
R21, R32, R41, R82, R90, R97: 18k; R_0603_1608Metric_Pad0.98x0.95mm_HandSolder
R36: 2.7k 1%; R_0603_1608Metric_Pad0.98x0.95mm_HandSolder
R38: 0; R_0603_1608Metric_Pad0.98x0.95mm_HandSolder
R42, R43: 100; R_0603_1608Metric_Pad0.98x0.95mm_HandSolder
R44: 33; R_0805_2012Metric_Pad1.20x1.40mm_HandSolder
R45, R46, R47, R59: 220; R_0603_1608Metric_Pad0.98x0.95mm_HandSolder
R50, R51, R53, R60, R61, R62, R63, R64, R68, R69, R70, R71, R72: 4.7k; R_0603_1608Metric_Pad0.98x0.95mm_HandSolder
R58: 470k; R_0603_1608Metric_Pad0.98x0.95mm_HandSolder
R65: 470; R_0603_1608Metric_Pad0.98x0.95mm_HandSolder
R89, R101, R102, R103: 75; R_0603_1608Metric_Pad0.98x0.95mm_HandSolder
R98: 4.7M; R_0603_1608Metric_Pad0.98x0.95mm_HandSolder
SW1: Jumper / Pin header 1x2 Pitch=2.54mm; Molex_KK-254_AE-6410-02A_1x02_P2.54mm_Vertical
SW2: SW_DIP_x02; SW_DIP_SPSTx02_Slide_9.78x7.26mm_W7.62mm_P2.54mm
SW3, SW4, SW5: SW_Push; SW_Tactile_SPST_Angled_PTS645Vx58-2LFS
TP1: TestPoint; TestPoint_Pad_D1.0mm
U1: MT48LC16M16A2; TSOP-II-54_22.2x10.16mm_P0.8mm
U2: AT91SAM7S256-AU; TQFP-64_10x10mm_P0.5mm; MPN AT91SAM7S256-AU-001
U3: EP3C25E144; ALTERA-QFP-145
U4: MAX3421E; LQFP-32_5x5mm_P0.5mm
U5: FE2.1-LQFP48; LQFP-48_7x7mm_P0.5mm
U6: ATtiny45-20PU; DIP-8_W7.62mm
U7: DS1307Z+; SOIC-8_3.9x4.9mm_P1.27mm
U8: LM3940IS-3.3; TO-263-3_TabPin2
U9: LD1117AS12TR; SOT-223-3_TabPin2
U10: LD1117AS25TR; SOT-223-3_TabPin2
U11: AD724; SOIC-16W_7.5x10.3mm_P1.27mm
X1: 27 MHz; Oscillator_SMD_EuroQuartz_XO91-4Pin_7.0x5.0mm_HandSoldering
X2: 12 MHz; Oscillator_SMD_EuroQuartz_XO91-4Pin_7.0x5.0mm_HandSoldering
Y1: 18.432 MHz; Crystal_HC49-U_Vertical
Y2: 32768 Hz; Crystal_C38-LF_D3.0mm_L8.0mm_Horizontal_1EP_style2
Y3: 4.433619 MHz; Crystal_SMD_HC49-SD

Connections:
+1V2: C42.2, C43.2, C44.2, C45.2, C46.2, C47.2, C48.2, C49.2, C68.2, L3.1, U3.5 (VCCINT), U3.29 (VCCINT), U3.34 (VCCINT), U3.38 (VCCINT), U3.45 (VCCINT), U3.61 (VCCINT), U3.70 (VCCINT), U3.78 (VCCINT), U3.84 (VCCINT), U3.102 (VCCINT), U3.116 (VCCINT), U3.124 (VCCINT), U3.134 (VCCINT), U3.138 (VCCINT), U9.2 (VO)
+1V2_PLL: C70.2, C71.2, C72.2, C73.2, L3.2, U3.1 (VCCD_PLL3), U3.37 (VCCD_PLL1), U3.73 (VCCD_PLL4), U3.109 (VCCD_PLL2)
+2V5: C35.2, C36.2, C37.2, C38.2, C69.2, U3.3 (VCCA3), U3.35 (VCCA1), U3.75 (VCCA4), U3.107 (VCCA2), U10.2 (VO)
+5V: C30.2, C32.2, C39.1, F1.1, F2.1, J17.4, L4.1, LS1.1, SW1.2 (B), U5.8 (VDD5), U5.41 (VBUSM), U7.8 (VCC), U8.1 (IN), U10.3 (VI)
+5V_JOY: F2.2, J1.7, J3.7
+5V_PAL: C75.2, C76.2, L4.2, U11.4 (AVCC), U11.5 (ENCD), U11.14 (DVCC)
+5V_USB: C33.2, C34.2, F1.2, J5.1 (VBUS), J6.1 (VBUS), J7.1 (VBUS), J8.1 (VBUS), R38.1, U5.43 (OVCJ5), U5.45 (OVCJ1)
+BATT: BT1.1 (+), U7.3 (VBAT)
/ARM_TCK: J14.4, R70.2, U2.53 (TCK)
/ARM_TDI: J14.8, R72.2, U2.33 (TDI)
/ARM_TDO: J14.6, R71.2, U2.49 (TDO)
/ARM_TMS: J14.2, R69.2, U2.51 (TMS)
/AUDIO_L: R10.1, U3.65 (IO/VREFB4N0)
/AUDIO_R: R11.1, U3.80 (IO/VREFB5N0)
/B: J9.3, R33.2, R34.2, R35.2, R37.2, R39.2, R40.2, R41.2
/Button1: R62.2, SW4.1, U2.5 (AD6)
/Button2: R63.2, SW5.1, U2.6 (AD7)
/CLK_12: U4.24 (XI), U5.22 (XIN), U6.2 (XTAL1/PB3), X2.3 (OUT)
/CLK_27: R12.1, R14.1, X1.3 (OUT)
/CONF_DATA0: U2.30 (PA9/PGMM1), U3.13 (IO/DATA0)
/CONF_DCLK: U2.20 (PA15/PGMD3), U3.12 (DCLK)
/CONF_DONE: R2.2, U2.36 (PA4/PGMNCMD), U3.92 (CONF_DONE)
/CONF_NCONFIG: R4.2, U2.31 (PA8/PGMM0), U3.14 (nCONFIG)
/CONF_NSTATUS: R3.2, U2.32 (PA7/PGMNVALID), U3.9 (nSTATUS)
/Composite: J4.S, R89.1
/DM_PUP: Q2.1 (G), U2.19 (PA16/PGMD4)
/FPGA_TCK: J13.1, R75.1, U3.16 (TCK)
/FPGA_TDI: J13.9, R74.2, U3.15 (TDI)
/FPGA_TDO: J13.3, U3.20 (TDO)
/FPGA_TMS: J13.5, R73.2, U3.18 (TMS)
/G: J9.2, R22.2, R23.2, R25.2, R26.2, R28.2, R31.2, R32.2
/HS: J9.13, R43.2
/MISO: J10.7 (DAT0), J16.7 (DAT0), U2.27 (PA12/PGMD0), U3.105 (IO/VREFB6N0), U4.15 (MISO)
/MOSI: J10.2 (CMD), J16.3 (CMD), U2.22 (PA13/PGMD1), U3.88 (CLK7/DIFFCLK_3n), U4.16 (MOSI)
/PIXEL_CLK: TP1.1, U3.33 (IO/RDN1)
/R: J9.1, R15.2, R16.2, R17.2, R18.2, R19.2, R20.2, R21.2
/RAM_A0: U1.23 (A0), U3.49 (IO/DIFFIO_B9n/DQ1B)
/RAM_A1: U1.24 (A1), U3.44 (IO/PLL1_CLKOUTn)
/RAM_A2: U1.25 (A2), U3.42 (IO/DQS1B/CQ1B#/CDPCLK2)
/RAM_A3: U1.26 (A3), U3.39 (IO/DIFFIO_B2p)
/RAM_A4: U1.29 (A4), U3.4 (IO)
/RAM_A5: U1.30 (A5), U3.6 (IO/DIFFIO_L3n/DATA1/ASDO)
/RAM_A6: U1.31 (A6), U3.8 (IO/DIFFIO_L4p/FLASH_nCE/nCSO)
/RAM_A7: U1.32 (A7), U3.10 (IO/DIFFIO_L6p/DQS0L/CQ1L/DPCLK0)
/RAM_A8: U1.33 (A8), U3.11 (IO/DIFFIO_L6n)
/RAM_A9: U1.34 (A9), U3.28 (IO/DIFFIO_L8p)
/RAM_A10: U1.22 (A10), U3.50 (IO/DIFFIO_B10n/DQ1B)
/RAM_A11: U1.35 (A11), U3.30 (IO/DIFFIO_L11p/DQS1L/CQ1L#/DPCLK1)
/RAM_A12: U1.36 (A12), U3.32 (IO/RUP1)
/RAM_BA0: U1.20 (BA0), U3.58 (IO/DIFFIO_B16p/DQ1B)
/RAM_BA1: U1.21 (BA1), U3.51 (IO/DIFFIO_B11p/DQ1B)
/RAM_CLK: U1.38 (CLK), U3.43 (IO/PLL1_CLKOUTp)
/RAM_DQ0: U1.2 (DQ0), U3.83 (IO/DIFFIO_R11p)
/RAM_DQ1: U1.4 (DQ1), U3.79 (IO/DIFFIO_R13n)
/RAM_DQ2: U1.5 (DQ2), U3.77 (IO/RDN3)
/RAM_DQ3: U1.7 (DQ3), U3.76 (IO/RUP3)
/RAM_DQ4: U1.8 (DQ4), U3.72 (IO/PLL4_CLKOUTn)
/RAM_DQ5: U1.10 (DQ5), U3.71 (IO/PLL4_CLKOUTp)
/RAM_DQ6: U1.11 (DQ6), U3.69 (IO/DIFFIO_B24p)
/RAM_DQ7: U1.13 (DQ7), U3.68 (IO/DIFFIO_B23n/DQS0B/CQ1B/CDPCLK3)
/RAM_DQ8: U1.42 (DQ8), U3.86 (IO/DIFFIO_R9n/DEV_OE)
/RAM_DQ9: U1.44 (DQ9), U3.87 (IO/DIFFIO_R9p/DEV_CLRn)
/RAM_DQ10: U1.45 (DQ10), U3.98 (IO/DIFFIO_R5n/INIT_DONE)
/RAM_DQ11: U1.47 (DQ11), U3.99 (IO/DIFFIO_R5p/CRC_ERROR)
/RAM_DQ12: U1.48 (DQ12), U3.100 (IO)
/RAM_DQ13: U1.50 (DQ13), U3.101 (IO/DIFFIO_R4n/nCEO)
/RAM_DQ14: U1.51 (DQ14), U3.103 (IO/DIFFIO_R4p/CLKUSR)
/RAM_DQ15: U1.53 (DQ15), U3.104 (IO/DQS0R/CQ1R/DPCLK7)
/RAM_DQMH: U1.39 (DQMH), U3.85 (IO/DIFFIO_R10p/DQS1R/CQ1R#/DPCLK6)
/RAM_DQML: U1.15 (DQML), U3.67 (IO/RDN2/DQ1B)
/RST: C29.2, J14.10, J18.6, R68.2, SW3.1, U2.39 (NRST), U3.89 (CLK6/DIFFCLK_3p), U4.12 (RES), U5.40 (XRSTJ)
/RTC_DN: R54.2, U5.37 (DM7)
/RTC_DP: R49.2, R56.2, U5.38 (DP7)
/RX_ARM: J15.2, U2.35 (PA5/PGMRDY)
/RX_FPGA: J12.2, J18.2, R55.1, R59.2, U3.31 (IO/VREFB2N0)
/SCK: R13.2, R29.1, R57.1, U2.21 (PA14/PGMD2)
/SD_CD: J10.10 (CARD_DETECT), J16.9 (DET_B), U2.48 (PA0/PGMEN0)
/SD_CLK: J10.5 (CLK), J16.5 (CLK), R57.2
/SD_DAT1: J10.8 (DAT1), J16.8 (DAT1), R64.2
/SD_DAT2: J10.9 (DAT2), J16.1 (DAT2), R53.2
/SD_VDD: C25.2, J10.4 (VDD), J16.4 (VDD), L2.2
/SD_WP: J10.11 (WRITE_PROTECT), U2.47 (PA1/PGMEN1)
/SS0: U2.28 (PA11/PGMM3), U4.14 (SS)
/SS1: J10.1 (CD/DAT3), J16.2 (DAT3/CD), U2.52 (PA31)
/SS2/FPGA: U2.29 (PA10/PGMM2), U3.127 (CLK9/DIFFCLK_5p)
/SS3/OSD: U2.43 (PA3), U3.91 (CLK4/DIFFCLK_2p)
/SS4/SD_DIRECT: U2.44 (PA2/PGMEN2), U3.90 (CLK5/DIFFCLK_2n)
/Switch1: R60.2, SW2.1, U2.4 (AD5)
/Switch2: R61.2, SW2.2, U2.3 (AD4)
/TAPE_IN: J11.2, R65.1, R67.1
/TAPE_OUT: C23.1, J11.3
/TX_ARM: J15.1, U2.34 (PA6/PGMNOE)
/TX_FPGA: J12.1, J18.7, R48.1, R52.1, U3.46 (IO/VREFB3N0)
/USBHUB1_DN: J5.2 (D-), U5.18 (DM1)
/USBHUB1_DP: J5.3 (D+), U5.19 (DP1)
/USBHUB2_DN: J6.2 (D-), U5.16 (DM2)
/USBHUB2_DP: J6.3 (D+), U5.17 (DP2)
/USBHUB3_DN: J7.2 (D-), U5.13 (DM3)
/USBHUB3_DP: J7.3 (D+), U5.14 (DP3)
/USBHUB4_DN: J8.2 (D-), U5.11 (DM4)
/USBHUB4_DP: J8.3 (D+), U5.12 (DP4)
/USBH_INT: U2.42 (PA30), U4.18 (INT)
/USB_DN: C8.1, R6.2, U2.57 (DDP)
/USB_DP: C7.1, R5.2, U2.56 (DDM)
/VGA_B0: R33.1, R34.1, R91.1, R92.1, U3.115 (IO/RDN4/DQ1T)
/VGA_B1: R35.1, R93.1, U3.120 (IO/DIFFIO_T19n/PADD1/DQ1T)
/VGA_B2: R37.1, R94.1, U3.121 (IO/DIFFIO_T17p/PADD4)
/VGA_B3: R39.1, R95.1, U3.125 (IO/DIFFIO_T13p/PADD12)
/VGA_B4: R40.1, R96.1, U3.132 (IO/DIFFIO_T10n/DATA2/DQ1T)
/VGA_B5: R41.1, R97.1, U3.133 (IO/DIFFIO_T10p/DATA3/DQ1T)
/VGA_G0: R22.1, R23.1, R83.1, R84.1, U3.106 (IO/DIFFIO_R1n/PADD20)
/VGA_G1: R25.1, R85.1, U3.110 (IO/DIFFIO_T23p/DQS0T/CQ1T/CDPCLK6)
/VGA_G2: R26.1, R86.1, U3.111 (IO/DIFFIO_T22p)
/VGA_G3: R28.1, R87.1, U3.112 (IO/PLL2_CLKOUTn)
/VGA_G4: R31.1, R88.1, U3.113 (IO/PLL2_CLKOUTp)
/VGA_G5: R32.1, R90.1, U3.114 (IO/RUP4/DQ1T)
/VGA_HS: R43.1, U3.119 (IO/VREFB7N0), U11.16 (HSYNC)
/VGA_R0: R15.1, R16.1, R76.1, R77.1, U3.135 (IO/DIFFIO_T9p/DATA4/DQ1T)
/VGA_R1: R17.1, R78.1, U3.137 (IO/DATA5/DQ1T)
/VGA_R2: R18.1, R79.1, U3.141 (IO/DIFFIO_T2p)
/VGA_R3: R19.1, R80.1, U3.142 (IO/DATA12/DQS1T/CQ1T#/CDPCLK7)
/VGA_R4: R20.1, R81.1, U3.143 (IO/PLL3_CLKOUTn/DQ1T)
/VGA_R5: R21.1, R82.1, U3.144 (IO/PLL3_CLKOUTp/DM1T)
/VGA_VS: R42.1, U3.136 (IO/VREFB8N0), U11.15 (VSYNC)
/VS: J9.14, R42.2
/~JOY0_B1: J1.6, U2.10 (PA18/PGMD6/AD1)
/~JOY0_B2: J1.9, U2.9 (PA17/PGMD5/AD0)
/~JOY0_DOWN: J1.2, U2.11 (PA21/PGMD9)
/~JOY0_LEFT: J1.3, U2.16 (PA20/PGMD8/AD3)
/~JOY0_RIGHT: J1.4, U2.13 (PA19/PGMD7/AD2)
/~JOY0_UP: J1.1, U2.14 (PA22/PGMD10)
/~JOY1_B1: J3.6, U2.23 (PA24/PGMD12)
/~JOY1_B2: J3.9, U2.15 (PA23/PGMD11)
/~JOY1_DOWN: J3.2, U2.37 (PA27/PGMD15)
/~JOY1_LEFT: J3.3, U2.26 (PA26/PGMD14)
/~JOY1_RIGHT: J3.4, U2.25 (PA25/PGMD13)
/~JOY1_UP: J3.1, U2.38 (PA28)
/~LED_ARM: R45.2, U2.41 (PA29)
/~LED_FPGA: R46.2, U3.7 (IO/VREFB1N0)
/~RAM_CAS: U1.17 (~CAS), U3.64 (IO)
/~RAM_CS: U1.19 (~CS), U3.59 (IO/DIFFIO_B17p/DQ1B)
/~RAM_RAS: U1.18 (~RAS), U3.60 (IO/DIFFIO_B17n/DQ1B)
/~RAM_WE: U1.16 (~WE), U3.66 (IO/RUP2/DQ1B)
GND: BT1.2 (-), C1.1, C2.1, C3.1, C4.1, C5.1, C7.2, C8.2, C9.2, C10.2, C13.2, C14.2, C15.2, C16.2, C17.1, C18.1, C19.1, C20.2, C21.2, C22.1, C25.1, C26.2, C27.2, C28.2, C29.1, C30.1, C31.1, C32.1, C33.1, C34.1, C35.1, C36.1, C37.1, C38.1, C39.2, C40.2, C41.1, C42.1, C43.1, C44.1, C45.1, C46.1, C47.1, C48.1, C49.1, C50.1, C51.1, C52.1, C53.1, C54.1, C55.1, C56.1, C57.1, C58.1, C59.1, C60.1, C61.1, C62.1, C63.1, C64.1, C65.1, C66.1, C67.1, C68.1, C69.1, C70.1, C71.1, C72.1, C73.1, C74.2, C75.1, C76.1, C81.2, D4.2 (A), J1.8, J1.10, J2.5 (GND), J2.6 (Shield), J3.8, J3.10, J4.R2, J5.4 (GND), J5.5 (Shield), J6.4 (GND), J6.5 (Shield), J7.4 (GND), J7.5 (Shield), J8.4 (GND), J8.5 (Shield), J9.0, J9.5, J9.6, J9.7, J9.8, J9.10, J10.3 (VSS), J10.6 (VSS), J10.12 (SHELL1), J10.13 (SHELL2), J11.1, J12.4, J13.2, J13.10, J14.3, J14.5, J14.9, J15.4, J16.6 (VSS), J16.10 (DET_A), J16.11 (SHIELD), J17.3, J18.1, Q3.2 (E), Q4.2 (E), R9.1, R36.2, R47.2, R67.2, R75.2, R98.1, R101.2, R102.2, R103.2, SW2.3, SW2.4, SW3.2, SW4.2, SW5.2, U1.6 (GNDQ), U1.12 (GNDQ), U1.28 (GND), U1.41 (GND), U1.46 (GNDQ), U1.52 (GNDQ), U1.54 (GND), U2.2 (GND), U2.17 (GND), U2.46 (GND), U2.60 (GND), U3.2 (GNDA3), U3.19 (GND), U3.22 (CLK0/DIFFCLK_0p), U3.23 (CLK1/DIFFCLK_0n), U3.24 (CLK2/DIFFCLK_1p), U3.25 (CLK3/DIFFCLK_1n), U3.27 (GND), U3.36 (GNDA1), U3.41 (GND), U3.48 (GND), U3.52 (CLK15/DIFFCLK_6p), U3.53 (CLK14/DIFFCLK_6n), U3.57 (GND), U3.63 (GND), U3.74 (GNDA4), U3.82 (GND), U3.94 (MSEL0), U3.95 (GND), U3.96 (MSEL1), U3.97 (MSEL2), U3.108 (GNDA2), U3.118 (GND), U3.123 (GND), U3.128 (CLK10/DIFFCLK_4n), U3.129 (CLK11/DIFFCLK_4p), U3.131 (GND), U3.140 (GND), U3.145 (PAD), U4.3 (GND), U4.19 (GND), U5.10 (VSS), U5.24 (VS_PLL), U5.39 (VSS), U6.4 (GND), U7.4 (GND), U8.2 (GND), U9.1 (GND), U10.1 (GND), U11.1 (STDN), U11.2 (AGND), U11.12 (SELECT), U11.13 (DGND), X1.2 (GND), X2.2 (GND), Y2.3, Y3.2
unnamed: C1.2, C2.2, C3.2, C4.2, C5.2, U2.8 (VDDOUT), U2.12 (VDDCORE), U2.24 (VDDCORE), U2.54 (VDDCORE), U2.64 (VDDPLL)
unnamed: C6.1, J2.3 (D+), R1.2, R5.1
unnamed: C6.2, J2.2 (D-), R6.1
unnamed: C9.1, R8.2, U2.63 (PLLRC)
unnamed: C10.1, R8.1
unnamed: C11.1, C13.1, R10.2
unnamed: C11.2, J4.R1
unnamed: C12.1, C14.1, R11.2
unnamed: C12.2, J4.T
unnamed: C15.1, U2.62 (XIN/PGMCK), Y1.1
unnamed: C16.1, U2.61 (XOUT), Y1.2
unnamed: C17.2, L1.2, U5.21 (VD_PLL)
unnamed: C18.2, L1.1, U5.6 (VD18), U5.25 (VD18_O), U5.28 (VD18)
unnamed: C19.2, U5.9 (VDD3_O), U5.15 (VD33), U5.20 (VD33), U5.26 (VD33), U5.31 (VD33), U5.36 (VD33), U5.42 (VD33)
unnamed: C20.1, R24.2, R27.2, U5.30 (DPU)
unnamed: C21.1, R30.2, U5.29 (DMU)
unnamed: C22.2, U4.22 (VBCOMP)
unnamed: C23.2, R52.2
unnamed: C24.1, C26.1, D4.1 (K), R66.1
unnamed: C24.2, R65.2
unnamed: C27.1, U7.1 (X1), Y2.2
unnamed: C28.1, U7.2 (X2), Y2.1
unnamed: C74.1, Q3.3 (C), R44.2
unnamed: C77.1, U11.6 (RIN)
unnamed: C77.2, R76.2, R77.2, R78.2, R79.2, R80.2, R81.2, R82.2, R101.1
unnamed: C78.1, U11.7 (GIN)
unnamed: C78.2, R83.2, R84.2, R85.2, R86.2, R87.2, R88.2, R90.2, R102.1
unnamed: C79.1, U11.8 (BIN)
unnamed: C79.2, R91.2, R92.2, R93.2, R94.2, R95.2, R96.2, R97.2, R103.1
unnamed: C80.1, U11.10 (COMP)
unnamed: C80.2, R89.2
unnamed: C81.1, R98.2, U11.3 (FIN), Y3.1
unnamed: D1.1 (K), R45.1
unnamed: D2.1 (K), R46.1
unnamed: D3.1 (K), R47.1
unnamed: J2.1 (VBUS), SW1.1 (A)
unnamed: J9.9, R38.2
unnamed: J17.1, R44.1
unnamed: J17.2, LS1.2
unnamed: JP1.2 (B), U2.40 (TST)
unnamed: Q2.3 (D), R1.1
unnamed: Q3.1 (B), R48.2
unnamed: Q4.1 (B), R58.1, R66.2
unnamed: Q4.3 (C), R59.1
unnamed: R9.2, U3.21 (nCE)
unnamed: R12.2, U3.54 (CLK13/DIFFCLK_7p)
unnamed: R13.1, U3.126 (CLK8/DIFFCLK_5n)
unnamed: R14.2, U3.55 (CLK12/DIFFCLK_7n)
unnamed: R27.1, U4.21 (D+)
unnamed: R29.2, U4.13 (SCK)
unnamed: R30.1, U4.20 (D-)
unnamed: R36.1, U5.27 (REXT)
unnamed: R50.2, U6.1 (~RESET~/PB5), U7.6 (SCL)
unnamed: R51.2, U6.6 (PB1), U7.5 (SDA)
unnamed: R54.1, U6.5 (AREF/PB0)
unnamed: R56.1, U6.7 (PB2)

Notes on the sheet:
RTC
FPGA
Power
SD card
Alternative microSD slot
Beeper
Clock
Tape
SDRAM memory
LEDs
USB controller and hub
WiFi
Debug
Buttons
IO ARM controller
VGA
PAL encoder
Power in / USB
AV out
Joystick ports
USB host ports

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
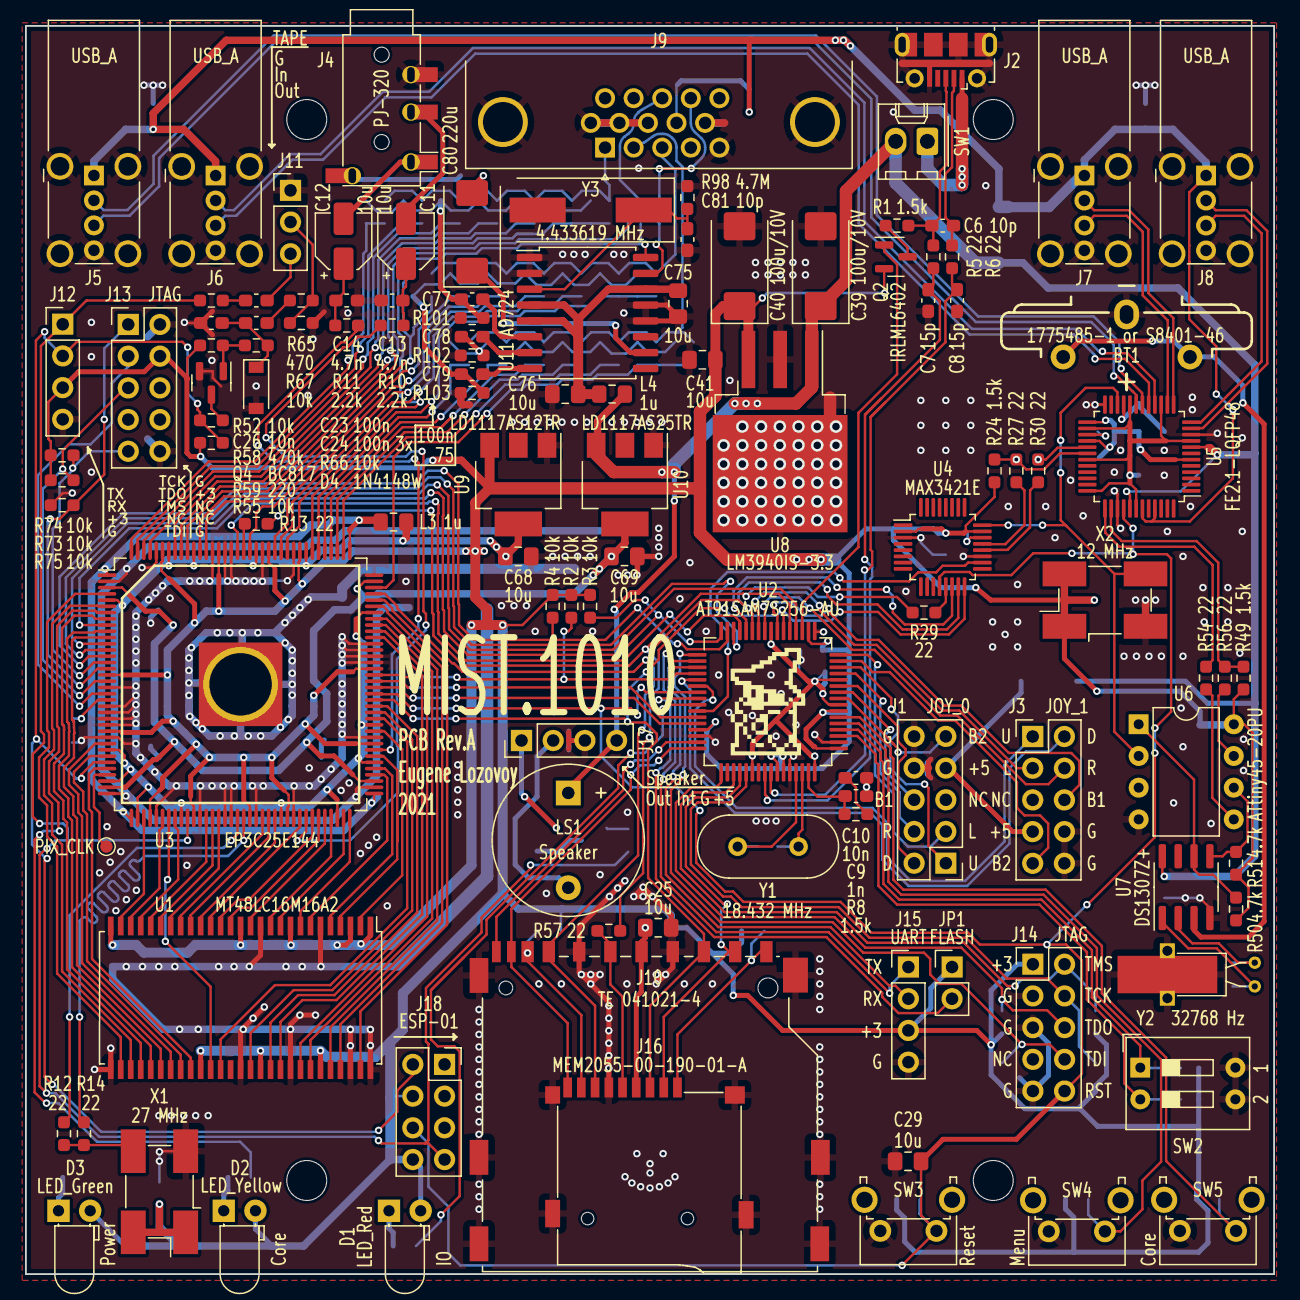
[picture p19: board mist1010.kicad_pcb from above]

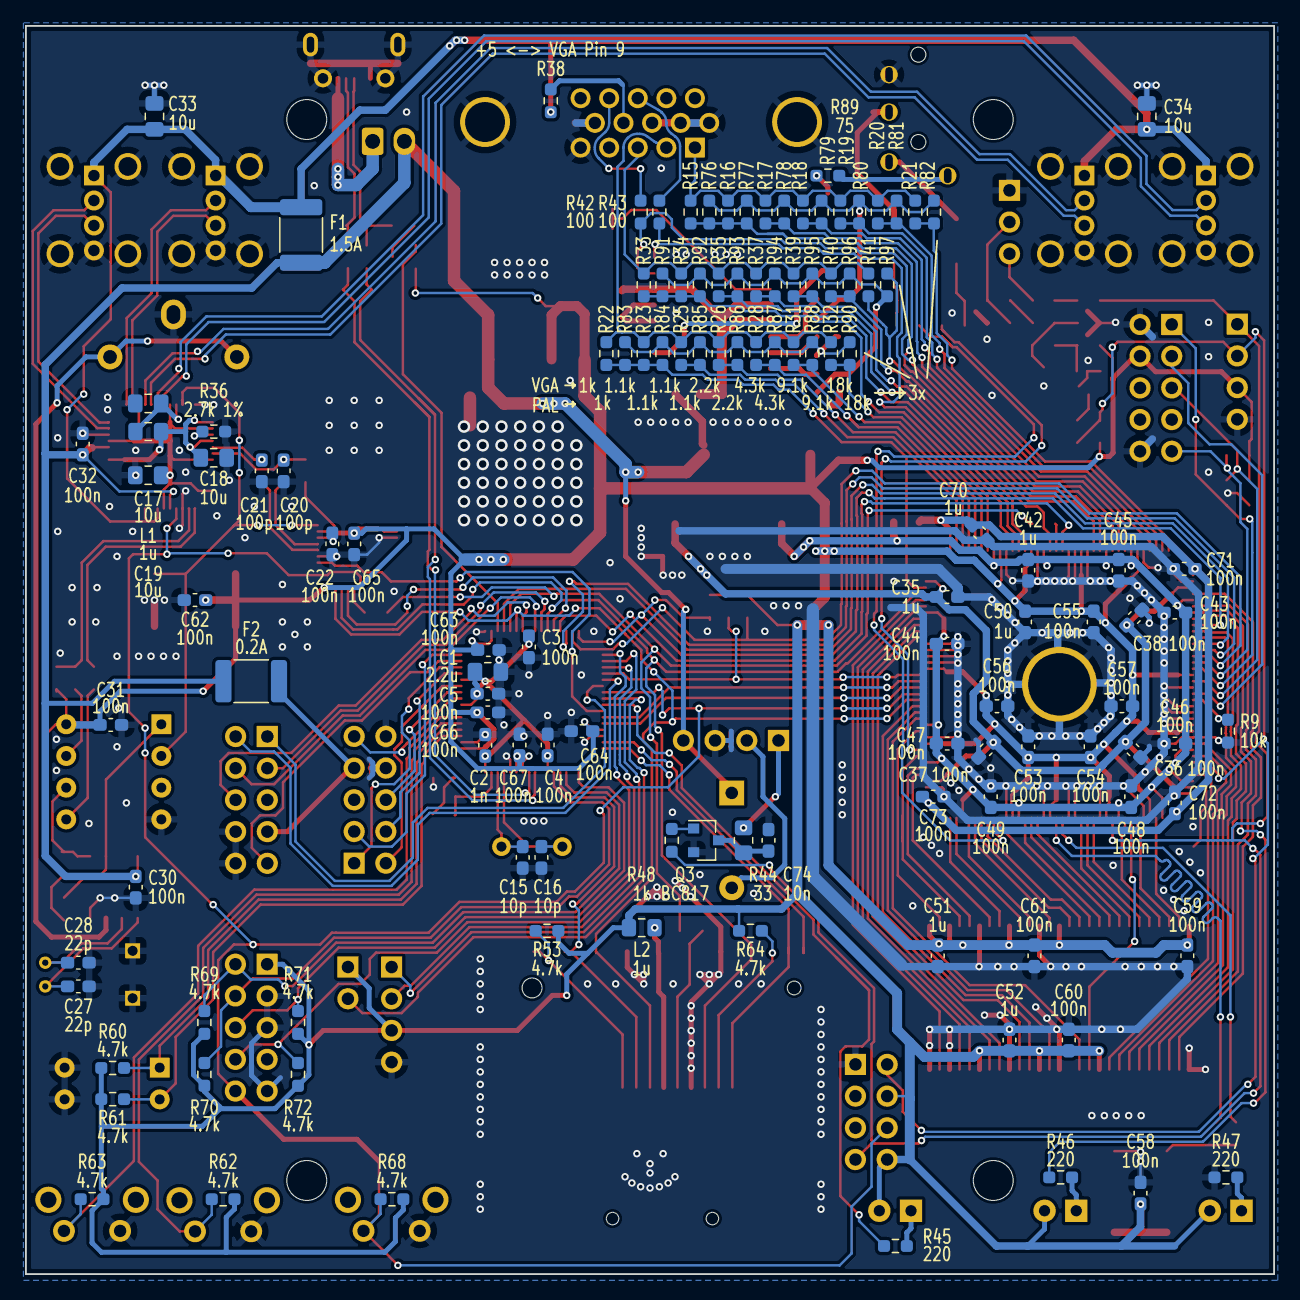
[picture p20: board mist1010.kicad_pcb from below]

Board: 2 copper layers, 100.0 x 100.0 mm, 242 parts (124 on the bottom side), 201 nets.

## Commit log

2021-08-26 update pcb rev.A
    [mist1010.kicad_pcb, mist1010.kicad_sch, mist1010_covers.kicad_pcb]
2021-10-18 add errata for pcb rev.A
2021-10-18 add pcb rev.A gerbers, bom and schematic
2022-05-25 update errata for pcb rev.A
2022-08-23 add pcb rev.A1
    [mist1010.kicad_sch]
2022-08-23 add pcb covers rev.A1
    [mist1010_covers.kicad_pcb, mist1010_covers.kicad_sch]
2022-08-23 add pcb rev.A2
    [mist1010.kicad_sch]
2022-08-23 remove outdated rev.A gerbers and pdfs
2025-05-18 add pcb rev.B
    [mist1010.kicad_sch, mist1010_covers.kicad_pcb, mist1010_covers.kicad_sch]
2025-05-18 add pcb rev.C
    [mist1010.kicad_sch, mist1010_covers.kicad_pcb, mist1010_covers.kicad_sch]
2025-05-18 add pcb rev C1 + release
    [mist1010.kicad_sch, mist1010_covers.kicad_pcb, mist1010_covers.kicad_sch]
